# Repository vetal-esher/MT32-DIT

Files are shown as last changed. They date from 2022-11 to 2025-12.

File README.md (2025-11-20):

# MT32-DIT
<h3>Adding digital output to legendary Roland MT-32</h3>
<p>Project status: ⬛⬛⬛⬛⬛⬛⬛⬛⬛⬛⬛⬛⬜ 95%</p>
<p>
This project can be considered part #2 of the digitalization of old synthesizers. In the first part I described <a href="https://github.com/vetal-esher/18bit-DIT">how you can add a  digital outpu</a>t to almost any synthesizer (where the DAC circuit uses standard L/R combined I2S) by using the AK4103AVF</p>

<p>
Roland MT-32, familiar to old gamers in the 90s and very rare now, is an even older device that uses a parallel DAC scheme that was 
quite common in Roland's D-series, which does not just convert the final stereo stream in-line, but also simultaneously performs 
the services of a DAC for the reverb IC.</p>

<h3>Digging demuxer logic</h4>

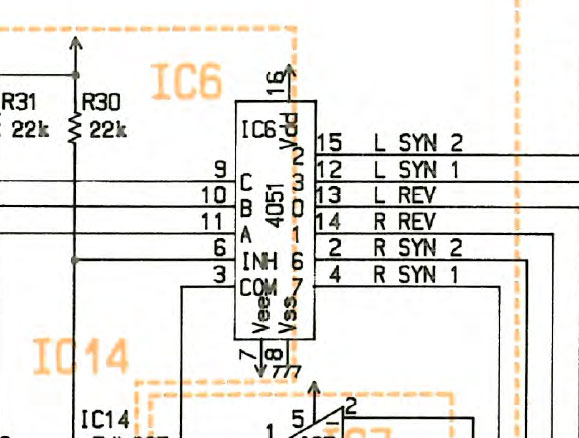
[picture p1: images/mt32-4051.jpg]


<p>
It turns out that we do not have direct access to the digital stream containing the final audio data. The PCM54HP receives a stream 
that sequentially contains not only clean left and right channels, but also separate reverb data for the left and right channels. 
It looks something like this (all frames are 16bit, order is assumed): [RSYN1][LSYN1][REV R][REV L][RSYN2][LSYN2][RSYN1][LSYN1][REV R][REV L][RSYN2] [LSYN2] etc.</p>
<p>
The advantage of a parallel DAC is that it works instantly, i.e. there is no delay at all in taking the current values 
from the (essentially) resistor assembly and the next moment doing the task of transforming a completely different picture. <strong>Edit: 
to tell the truth, there IS small delay required to let the output settled the final value.</strong>
</p>
<p>The widely known CD4051 is engaged in demultiplexing all this porridge of audio data. Channel switching in the CD4051 is carried out 
through the control lines mixed from LA and Reverb chips SH1 SH2 SH2 (SH - Sample / Hold), as well as the INH line, which turns on and off 
all channels. At the output of the demuxer, three pairs of analog channels are formed, which are then mixed and undergo final 
processing in a low-pass filter. The LP filter should have a flat amplitude response in the 0-20kHz range and a high attenuation above 20kHz.
</p>

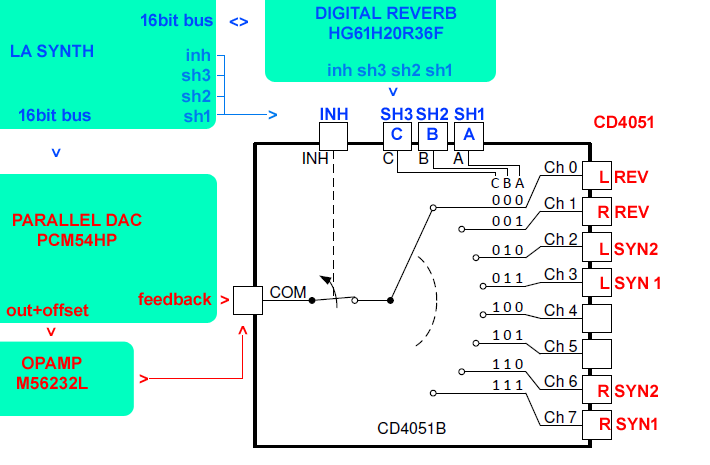
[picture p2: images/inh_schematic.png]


<p>
Bit depth and sampling frequency of MT-32 according to the declared characteristics - 15bit 32kHz. In the first version of MT-32 
(the so-called "old"), the last (actually, LSB) 16th bit at the PCM54HP input is shorted to ground, and for that (15bit) reason the 14th bit fell out 
in the data bus itself (counting from zero). However, for us, the frame width will always be 16 bits (the 2nd MT-32 version has full 16bit bus). Theoretically, the channel  switching frequency 0-1-2-3-4-5-6-7 each time triggers a 0/1 state change in control signal A, so you can 
expect 128kHz on this line,  64kHz on line B, and C with 32kHz respectively. But we don't know the order of the frames. Even if we 
sequentially record all the states of the parallel bus, it will be useless if we do not know the order of switching ABC. In practice, 
without a three-channel oscilloscope, you can try to catch the states of at least two of the three lines (A and C), and then record 
the AB and BC, A and INH sequences in order to further bring the picture into one.
</p>
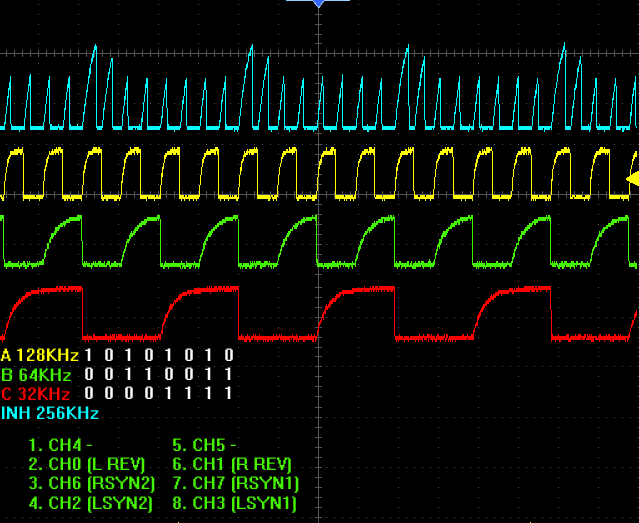
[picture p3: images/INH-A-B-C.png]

<p>

So now we know the frame order: [L REV][RSYN2][LSYN2][R REV][RSYN1][LSYN1], [L REV][RSYN2][LSYN2][R REV][RSYN1][LSYN1] .. etc. 
If you listen to these pins in analog, it becomes clear that SYN1 is a clean signal, REV is a reverb return. SYN2 appears to be 
analog as well, but too quiet to be recorded legibly; but since SYN2 is also mixed into the final mix, we'll do that too. 
By the way, if you look at the unused outputs of the CD4051 CH4 and CH5, there will be [almost] crisp 32kHz:

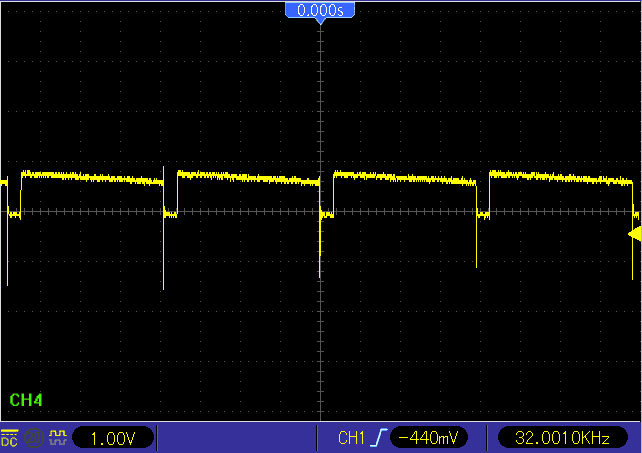
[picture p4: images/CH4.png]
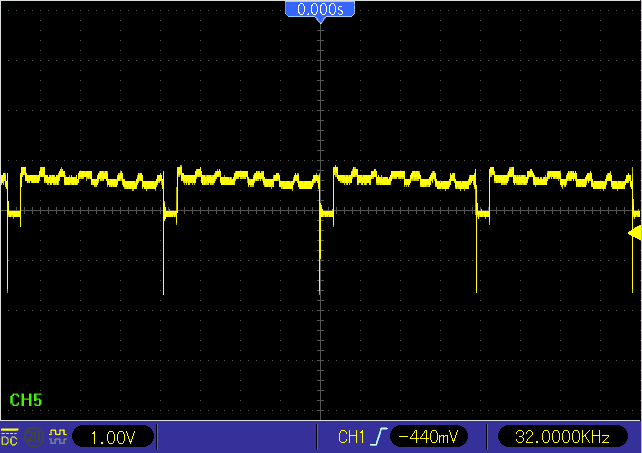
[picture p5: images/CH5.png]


<p>The INH control signal operates at a frequency of 256kHz, which means we will need to read all ports at this frequency. 
Disabling all channels is necessary so that there is no false triggering on rising edges @ABC states, when INH=1 tells us that 
we don’t need to send anything to serial. With INH=0, we must read the bus, and depending on the states of ABC, scatter it to 
the appropriate output. Ideally, we need to define the beginning of frame (we take the highest INH peak for the reference frame)
and mix all L / R frames into two final ones. But for the test, you can start by sending two frames with a clean non-reverberated 
information (RSYN1, LSYN1). At first I thought to bother with the sequence' start detection, but then I omitted this part, because,
even if the logic begins to run in the middle, defining LSYN1 as the end of the sequence we will reset the counters and then start 
working in the correct order. The logic in this case will look something like this (I will use a pseudo-language here with a syntax 
that is clear to everyone):</p>

<pre>
(R,L)=(0,0);
(FLAG_RSYN1,FLAG_LSYN1,FLAG_RSYN2,FLAG_LSYN2,FLAG_RREV,FLAG_LREV)=(0,0,0,0,0,0);
(RSYN1,LSYN1,RSYN2,LSYN2,RREV,LREV)=(0,0,0,0,0,0);
while (256kHz_cycle) {
	input=read(PCM54_parallel);
	A=read(CD4051_A); B=read(CD4051_B); C=read(CD4051_C); INH=read(CD4051_INH);

	#INH==0 enables output
	if (INH==0) {
		if (A==1 && B==1 && C==0) {
			RSYN2=input; FLAG_RSYN2=1; #RSYN2
		}
		elsif (A==0 && B==1 && C==0) {
			LSYN2=input; FLAG_LSYN2=1; #LSYN2
		}
		elsif (A==0 && B==0 && C==1) {
			RREV=input; FLAG_RREV=1;   #RREV
		}
		elsif (A==0 && B==0 && C==0) {
			LREV=input; FLAG_LREV=1;   #LREV
		}
		elsif (A==1 && B==1 && C==1) {
			RSYN1=input; FLAG_RSYN1=1; #RSYN1
		}
		elsif (A==0 && B==1 && C==1) {
			LSYN1=input; 		   #LSYN1 this is the last channel in frame
			(FLAG_RSYN1,FLAG_LSYN1,FLAG_RSYN2,FLAG_LSYN2,FLAG_RREV,FLAG_LREV)=(1,1,1,1,1,1);
		}

		if (FLAG_RSYN1==1 && FLAG_LSYN1==1 && FLAG_RSYN2==1 && FLAG_LSYN2==1 && FLAG_RREV==1 && FLAG_LREV==1) {

			#in merge there will be magic
			L=merge(LSYN1,LSYN2,LREV);
			R=merge(RSYN1,RSYN2,RREV);
			write_serial(R,L); 

			#reset channel flags
			(FLAG_RSYN1,FLAG_LSYN1,FLAG_RSYN2,FLAG_LSYN2,FLAG_RREV,FLAG_LREV)=(0,0,0,0,0,0);
		}
	}
}
</pre>

<h3>Hardware part</h3>

<p>Schematically, the plan of the entire project was drawn like this:</p>
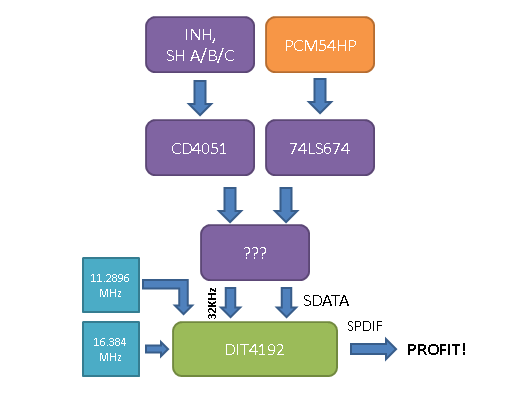
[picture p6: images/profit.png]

<p>
There is only one magic figure involved in this plan, and here, I will honestly say, giant constructions of logic which must perform the task of mixing digital streams comes to mind. I was told that I should stop doing garbage and learn a programmable FPGA. All of the DAC and INH/A/B/C signals are CMOS-level, so we need to convert them to TTL by CD4050B. By the way, we will get fixed levels of INH after CD4050:
</p>
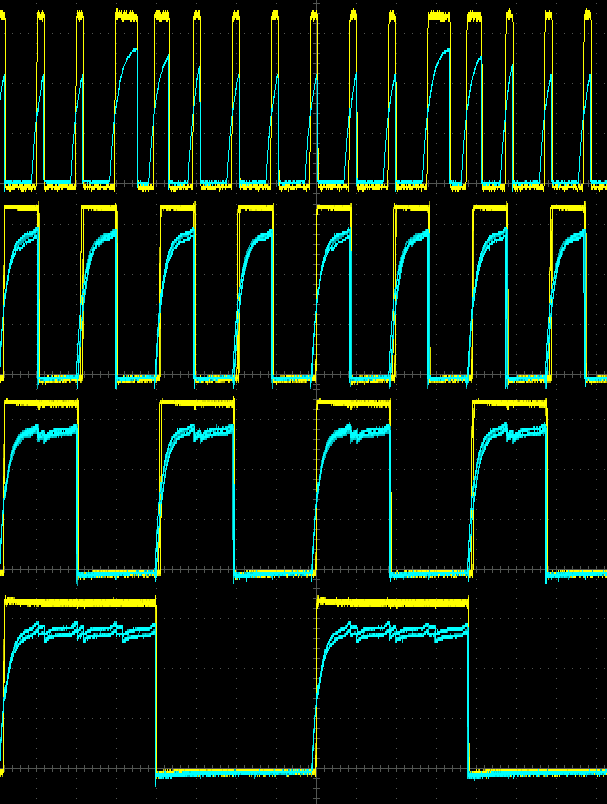
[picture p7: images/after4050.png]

<h4>DIT</h4>
<p>
Since we are dealing with 16 bits, a large number of DITs can be used, as they all work at least with 16-bit RJ. For these purposes, I chose DIT4192, because I have it  already available after experimenting with the 18-bit DIT, but you can skip mounting 4192 if you don't have it (details below). Settings are typical:
<table border="1">
<tr><th colspan="2">DIT4192 Hardware mode</th></tr>
<tr><td>Mode operation</td><td>Slave (SYNC and SCLK are inputs)</td></tr>
<tr><td>Format</td><td>16-Bit Right-Justified</td></tr>
<tr><td>Sampling frequency</td><td>32kHz</td></tr>
<tr><td>Master clock</td><td>16.384MHz (512*fs)</td></tr>
<tr><td>Bit clock</td><td>1.024MHz (16*2*32KHz)</td></tr>
</table>
</p>

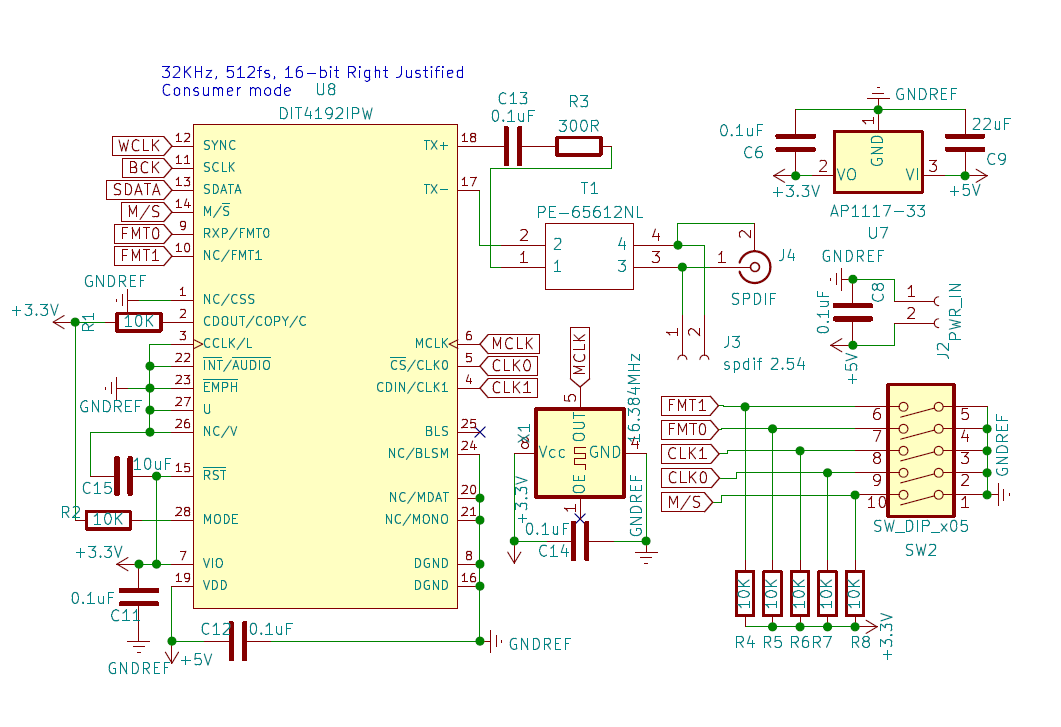
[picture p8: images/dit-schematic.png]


<h3>Magic part</h3>
<p>The FPGA <a href="https://wiki.sipeed.com/hardware/en/tang/Tang-Nano-9K/Nano-9K.html">TangNano9K</a> was chosen for the magic part, so the "profit" plan was drawn:</p>
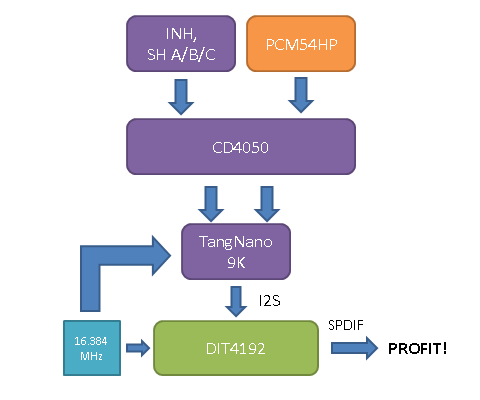
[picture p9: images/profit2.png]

<p>And then the complete schematic of the "magic" part was done. Note the I2S connector, you can completely skip DIT4192 in schematic and use your favorite external DIT, or even just transport I2S to I2S receiver. I tested I2S with external WM8804 DIT board and it works perfectly.</p>
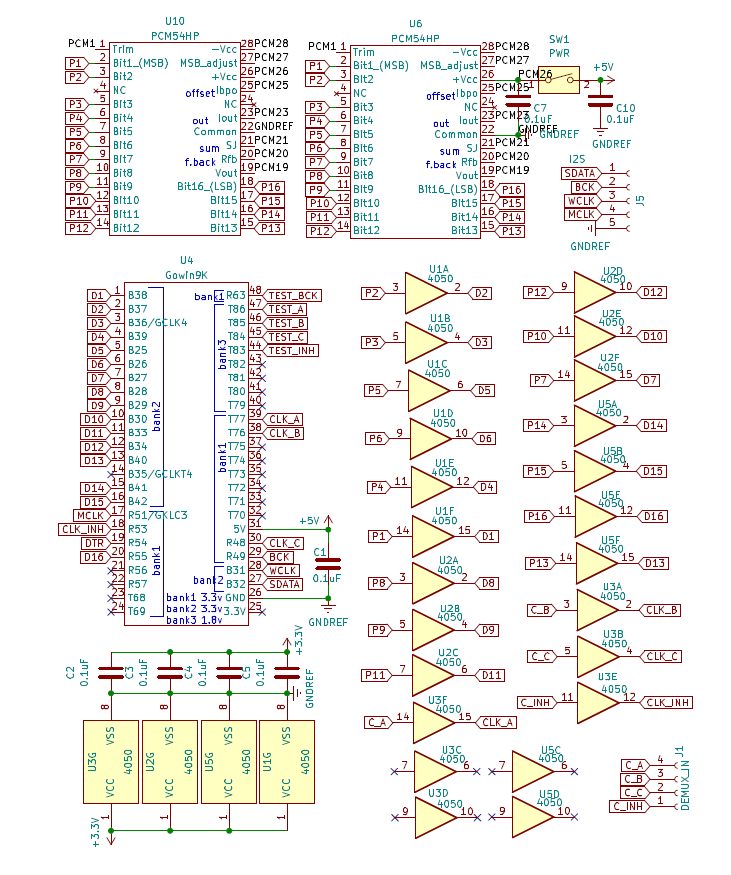
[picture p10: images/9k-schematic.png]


<h3>Making prototypes</h3>
<p>I started with sandwich-like breadboard, trying to split the CMOS-TTL logic from TangNano. Different methods, using couple of variants (voltage dividers) and CD4050 were tried..</p>
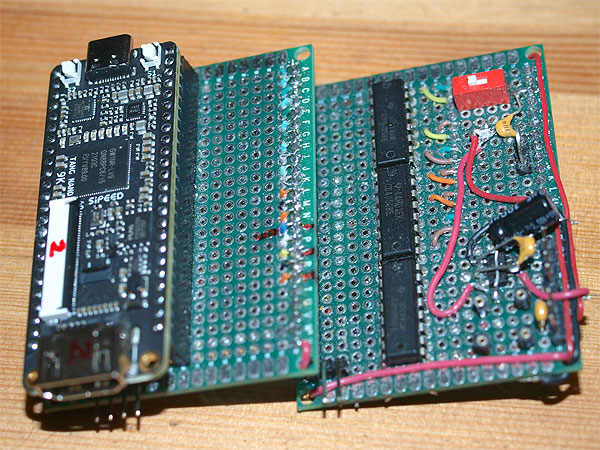
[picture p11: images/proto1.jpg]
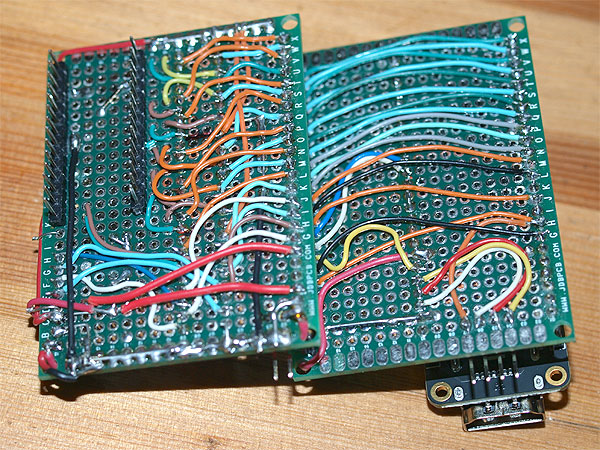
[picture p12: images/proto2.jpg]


.. and then, when i finally decided to use CD4050, i have projected the PCB. The PCBs were made quick at PCBway factory, and i must say their quality is awesome, even for such pet projects like mine :) 

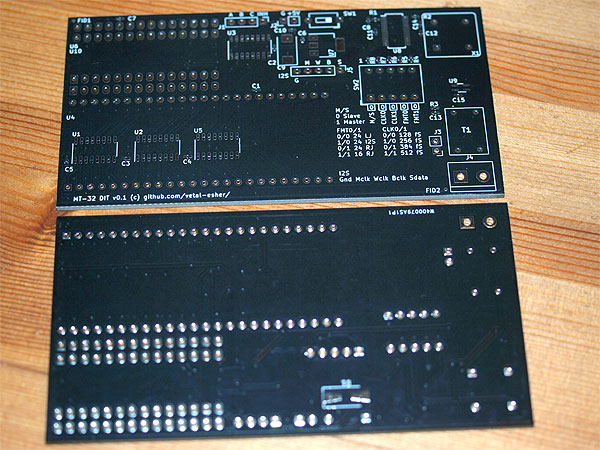
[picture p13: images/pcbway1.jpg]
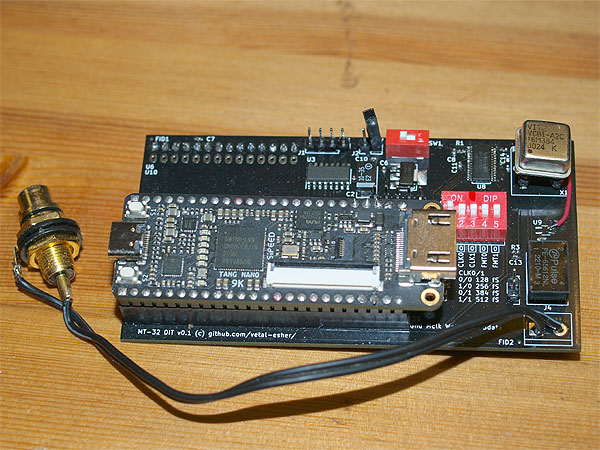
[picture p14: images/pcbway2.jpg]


<p>Final design assumes, that the original PCM54HP will be desoldered from MT-32 mainboard, and then socketed on second footprint right on DIT pcb. After that, MT32-DIT can be soldered or socketed on MT-32 mainboard. But for now, we'll just put on the DIT board right over PCM54HP IC.</p>

<h2>Partlist</h2>
<table border=1>
	<tr><th>Reference</th><th>Total</th><th>Value</th><th>Package</th></tr>
	<tr><td>X1</td><td>1</td><td>16.384MHz</td><td>Oscillator DIP-8</td></tr>
	<tr><td>U1, U2, U3, U5</td><td>4</td><td>CD4050</td><td>SO-16</td></tr>
	<tr><td>U4</td><td>1</td><td>Gowin 9K</td><td></td></tr>
	<tr><td>U6</td><td>1</td><td>PCM54HP**</td><td>DIP-28</td></tr>
	<tr><td>U8</td><td>1</td><td>DIT4192IPW***</td><td>SSOP-28</td></tr>
	<tr><td>U7</td><td>1</td><td>AP1117-33</td><td>SOT223-3_TABPIN2</td></tr>
	<tr><td>U10</td><td>2</td><td>PinHeader 1x28</td><td>P2.54mm</td></tr>
	<tr><td>T1</td><td>1</td><td>PE-65612NL***</td><td>PE-65612NL</td></tr>
	<tr><td>SW1</td><td>1</td><td>PWR SW</td><td>SW_DIP_SPSTx01_P2.54mm</td></tr>
	<tr><td>SW2</td><td>1</td><td>CFG SW***</td><td>SW_DIP_SPSTx05_P2.54mm</td></tr>
	<tr><td>R1, R2, R4, R5, R6, R7, R8</td><td>7</td><td>10K ***</td><td>0402</td></tr>
	<tr><td>R3</td><td>1</td><td>300R ***</td><td>0402</td></tr>
	<tr><td>J1</td><td>1</td><td>PinHeader 1x04</td><td>P2.54mm</td></tr>
	<tr><td>J2, J3***</td><td>2</td><td>PinHeader 1x02</td><td>P2.54mm</td></tr>
	<tr><td>J4</td><td></td><td>DNP*</td><td></td></tr>
	<tr><td>J5</td><td>1</td><td>PinHeader 1x05</td><td>P2.54mm</td></tr>
	<tr><td>C1, C2, C3, C4, C5, C6, C7, C8, C10, C11, C12***, C13***, C14</td><td>13</td><td>0.1uF</td><td>0402</td></tr>
	<tr><td>C15***</td><td>1</td><td>10uF</td><td>0402</td></tr>
	<tr><td>C9</td><td>1</td><td>10-22uF</td><td>CP_EIA-7343-43</td></tr>
</table>
<p>If only specific component can be skipped, it's marked within "Reference" column, otherwise all components can be skipped if mark is in "Value" column.</p>
<p><strong>*</strong> - Do Not Place</p>
<p><strong>**</strong> - optional, no need if DIT pcb soldered on top of the original DAC</p>
<p><strong>***</strong> - optional, no need if DIT4192 is not available and you use external DIT</p>

<h3>Learning VERILOG</h3>

<p>I did not have any experience in designing FPGA projects, and did not knew about verilog language anything. But it appeared, that my pseudo-language logic described above is almost verilog-like! So, after few weeks, the very first working code was written.</p>

<details>
  <summary>First verilog code:</summary>	

<pre>
module top (
        input mclk,             //master clock //pin 51
        input clk_inh,          //256kHz INH clk input //pin 53
        input [2:0] ch_id,      //cd4051 sample/hold controls a/b/c 128/64/32kHz //pin a 77 b 76 c 48
        input [15:0] dac,       //parallel input from dac
	input sys_rst_n,        //reset input
	output wire dtr,        //data ready flag //pin54
        output sdata,           //16bit i2s sdata output  //pin 49
        output wire wclk,       //i2s word select lrck output 32kHz //pin 31
        output wire bck         //i2s bit clock output 1024MHz //pin32
);

wire [31:0] data;

dac_decoder dac1(
	.clk_inh(clk_inh),.ch_id(ch_id),.dac(dac),.data(data),.rst_n(sys_rst_n),.dtr(dtr)
);

i2s_serializer ser1 (
	.mclk(mclk),.sdata(sdata),.wclk(wclk),.bck(bck),.data(data),.rst_n(sys_rst_n)
);

endmodule

module i2s_serializer (
        input mclk,             	//master clock 16.384MHz
	input [31:0] data,		//input channels register 
	input wire rst_n,		//reset button	
	output reg sdata,   	    	//i2s sdata output
        output reg wclk,        	//i2s word select lrck output mclk/512 = 32kHz
        output wire bck         	//[3] bit'mclk. i2s bit clock output 
					//16bit * 2 * 32000 = 1.024 MHz (16.384/16)
);
reg [31:0] mclk_counter;       		//32bit counter
assign bck=mclk_counter[3];     	//1.024MHz divide
reg [31:0] data_buf;			//i2s output buffer 
reg [4:0] cbit;				//0-15 current bit counter
			
initial begin
	mclk_counter<=0; cbit<=0; wclk<=0; data_buf<=0;
end

always  @(posedge mclk,negedge rst_n) begin
	if(!rst_n) begin mclk_counter<=0; end 
	else begin mclk_counter<=mclk_counter+1; end
end

//i2s WCLK=0 left, =1 right
always  @(negedge bck) begin					//send sdata from buffer
	if (wclk==0) begin sdata<=data_buf[31-cbit]; end 	//LSYN send
	else if (wclk==1) begin sdata<=data_buf[15-cbit]; end	//RSYN send
	cbit<=cbit+4'b01;
	if (cbit==15 && wclk==0) 
		begin cbit<=0; wclk<=1; end			//LSYN1 end
	else if (cbit==15 && wclk==1) 
		begin cbit<=0; wclk<=0; data_buf<=data; end 	//RSYN1 end, new buffer read
end
endmodule

module dac_decoder (
	input wire rst_n,
        input clk_inh,          	//256kHz INH clk input
        input [2:0] ch_id,    		//cd4051 sample/hold controls a/b/c
        input [15:0] dac,       	//parallel input from dac
	output reg [31:0] data,		//32 bit
	output reg dtr			//data ready flag
);
reg [15:0] ch0;				//LREV
reg [15:0] ch6;				//RSYN2
reg [15:0] ch2;				//LSYN2
reg [15:0] ch1;				//RREV
reg [15:0] ch7;				//RSYN1
reg [15:0] ch3;				//LSYN1
initial begin
	ch0<=0; ch1<=0; ch2<=0; ch3<=0; ch6<=0; ch7<=0; dtr<=0; data<=0;
end

always  @(negedge clk_inh,negedge rst_n) begin
	if(!rst_n) begin
		dtr<=0; data<=0;
	end 
	else begin
	case (ch_id)
		4 : begin dtr<=0; end 			// empty
		0 : begin dtr<=0; ch0<=dac; end 	// LREV
		6 : begin dtr<=0; ch6<=dac; end 	// RSYN2 
		2 : begin dtr<=0; ch2<=dac; end 	// LSYN2
		5 : begin dtr<=0; end 			// empty
		1 : begin dtr<=0; ch1<=dac; end 	// RREV
		7 : begin dtr<=0; ch7<=dac; end 	// RSYN
		3 : begin dtr<=1; ch3<=dac; data = {dac,ch7}; end // LSYN
	endcase
	end
end
endmodule
</pre>

</details>

The <a href="https://www.youtube.com/watch?v=VIkrG32c1l0">first video</a> of clean capture (sorry for low volume, it was at night) (clean stereo, no reverb).

<h3>Mixing 6 digital channels to stereo pair</h3>

The simplest logic of audio mixing is summing the levels. This works in digital too. Remember, that actual bitwidth of "old" Roland MT-32 is 15 (LSB bit is tied to the GND. So, 
we can use 17-bit buffer to sum all 3 channels. Also i implemented "reverb on/off" switch tied to second button at TangNano9K devboard (first one is RESET button). 
OFFSET parameter used to avoid digital overflow problem when summing all channels.

<pre>
reg signed [15:0] lsyn1, lsyn2, rsyn1, rsyn2, rrev;	//channels from LA32 and Reverb ICs
reg signed [15:0] left,right;
reg signed [16:0] l,r;

initial begin
    data<=0; rrev<=0; rsyn1<=0; lsyn2<=0; rsyn2<=0; 
    l<=0; r<=0; left<=0; right<=0; dtr<=0;
end

localparam signed [15:0] OFFSET = 16'd8192; //Digital DC offset fix

always  @(negedge clk_inh) begin
	if (!rst_n) begin
		data<=0; dtr<=0;
	end else begin
	case (ch_id)
     		7 : begin // RSYN1
			rsyn1<=dac; dtr<=1;
			left <= l[15:0]-OFFSET; right <= r[15:0]-OFFSET;
		    end 
		6 : begin rsyn2<=dac; dtr<=0; end // RSYN2
		5 : begin data<={left,right}; dtr<=0; end // empty
		4 : begin dtr<=1; end // empty
		3 : begin lsyn1<=dac; dtr<=1; end // LSYN1
		2 : begin lsyn2<=dac; dtr<=1; end // LSYN2
		1 : begin rrev<=dac;  dtr<=1; end // RREV
		0 : begin dtr<=0; // LREV
			if (!rev_sw) begin  l<=lsyn1; r<=rsyn1;  end else 
			begin l<=lsyn1+lsyn2+dac; r<=rsyn1+rsyn2+rrev; end
 	     	end 
	endcase
	end
end

</pre>
</details>

<h3>Possible problems</h3>

<h4>Clicks</h4>
<p>At the final stage, i found that the frequency of DTR (the flag that signals about full frame cycle pass) is slightly faster than WCLK (smth about 32.0010kHz@DTR vs exact 32.0000kHz@WCLK). 
I
</p>



<p>The first reason is that you cannot operate with registers with multiple actions in one clock tick. You need pipeline. So, mixing logic with OFFSET must be separated.

Also, within this logic, you need to avoid update output data register when it might be in "read status" at serializer. Setting values need some time to be set, so we don't update the data when it is in stage of reading.

<p>After that, recording more than 3 hours showed that the clicks were gone, completely.</p>
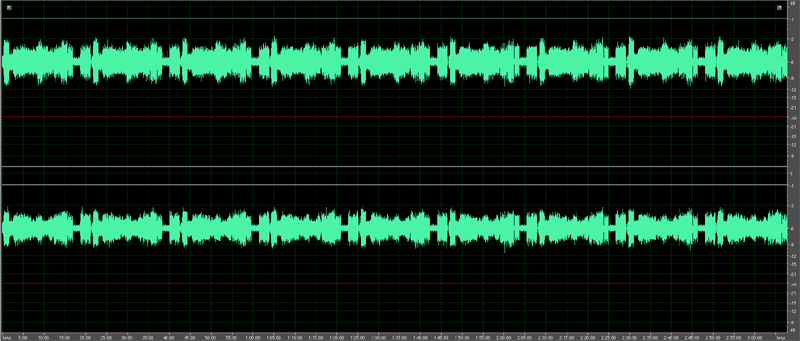
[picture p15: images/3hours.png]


<h4>Desync</h4>
<p>Another problem can appear, there <strong>might be</strong> desync that can produce more clicks than useful audio data. The source of problem is in unstable crystal oscillator - you need to check the DIT pcb for shorts and leakages. </p>
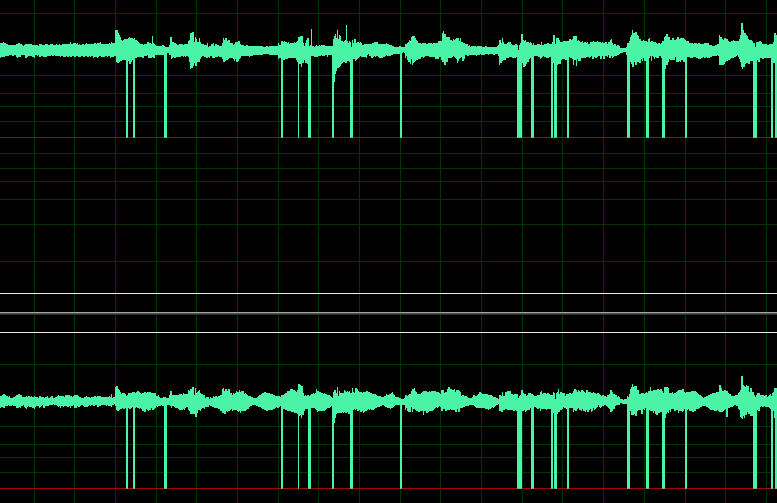
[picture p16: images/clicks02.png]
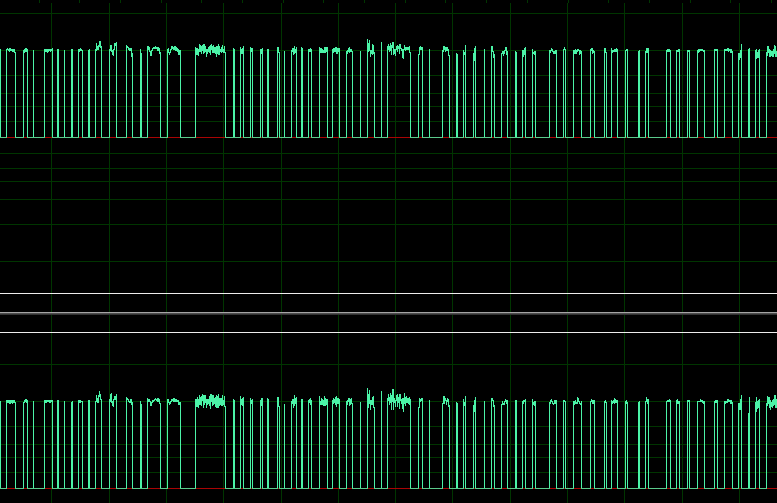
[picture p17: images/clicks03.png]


<h4>Digital DC offset</h4>

<p><strong>Updated 15.10.2025</strong></p> It's seems that there's nothing we can do (at least with 1st revision of MT-32) since DAC's LSB bit is tied to ground and there is 14 bit dropped in DAC schematic. When LSB bit will be used, there will be no DC offset at all. After all, i checked the PCB and found that the Bit14(=D14) used in schematic bus between LA32/Reverb/DAC - on real PCB has no route out from LA32 and Reverb chips, and the pin 27 (D14) on LA32 has no activity on oscilloscope at all.
You can slightly lower DC offset decrementing each sample value by 16344 (that the value of amplitude zero when there's no sound from MT-32), but this will give you only 6dB fix.
</p>

<h4>Post digital LPF processing</h4>

<p><strong>To be continued</strong></p>

<h2>Mounting</h2>

<strong>Bad contact problem.</strong> It was nightmare to spend hours to find the source of noisy sound. After weeks(!) of resultless tries, i found that the way i put the pcb over original DAC is not reliable at all - some pins was not connected . 

<p><strong><a href="audio/clean.mp3">Example of clean sound.</a></strong></p>
<p><strong>And <a href="audio/dirty_1.mp3">this is what you should hear</a> when some bits are not connected</strong></p>

<p>To avoid bad contact problem, the only way is to desolder DAC and socket it on the MT32-DIT pcb. This process is very hard without proper experience. First of all, you need to replace nearby caps with lower profile equivalents. Film caps are perfectly fit this objective. Then desolder the DAC itself.</p>

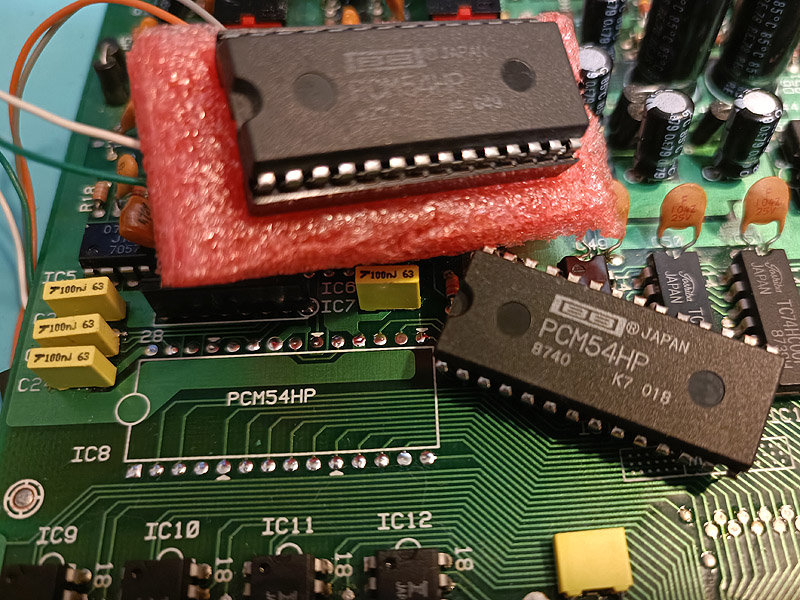
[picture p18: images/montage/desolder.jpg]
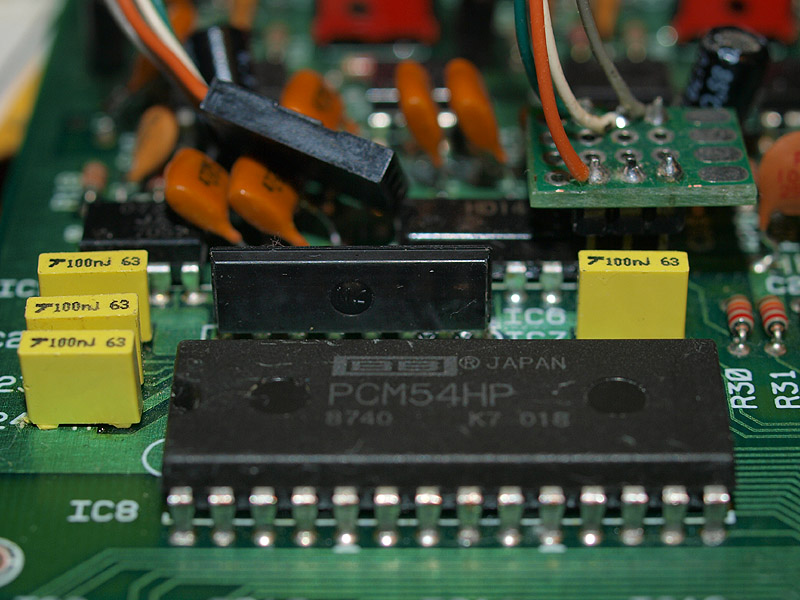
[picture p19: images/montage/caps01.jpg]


<p>While replacing the caps, it is time to think about picking A/B/C/INH directly from CD4051 demuxer. When you solder wires directly to DIP-package pins, wires tend to break when they bend, so i decided to solder a small protoboard over CD4051 for easy access to this signals.

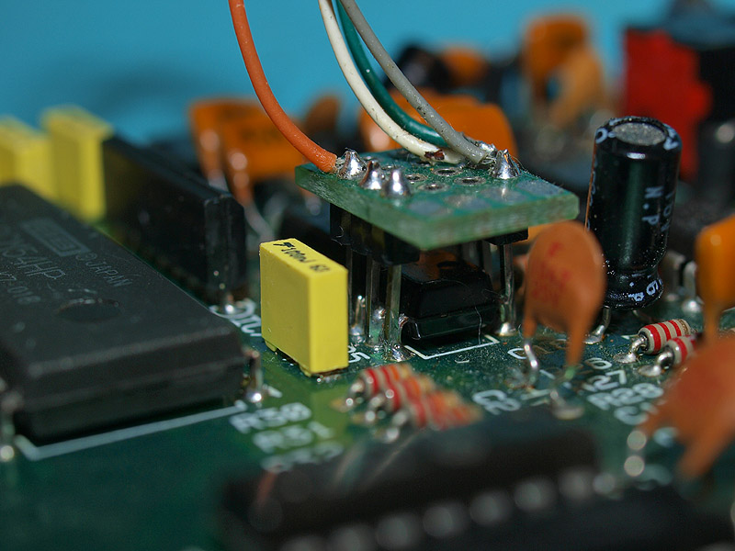
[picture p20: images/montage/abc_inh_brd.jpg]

<p>I used PBD (2-row) 2.54 female headers for socketing the DIT pcb in DAC place. One row, of course, needs to be removed. Why 2-row? Just because i had much more PBD headers than PBS. You can use PBS if you want. Then socket the PCM54HP on DIT pcb.</p>

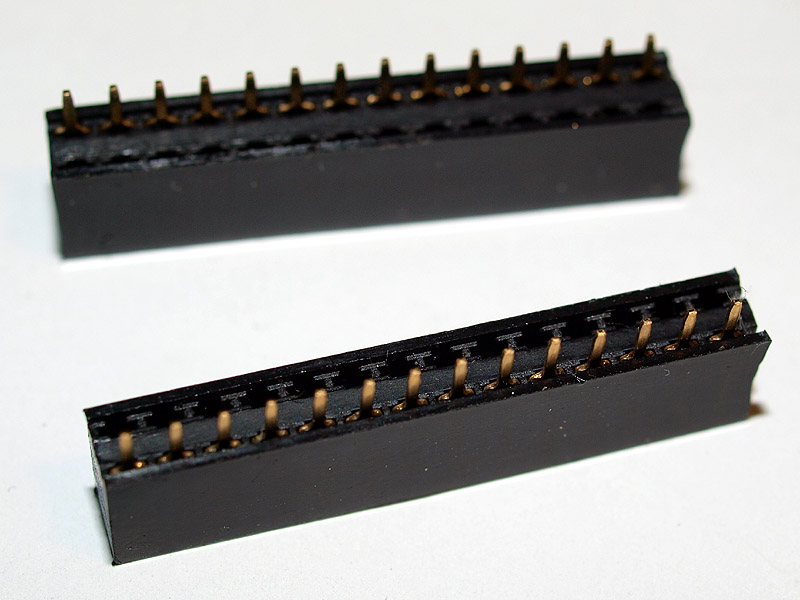
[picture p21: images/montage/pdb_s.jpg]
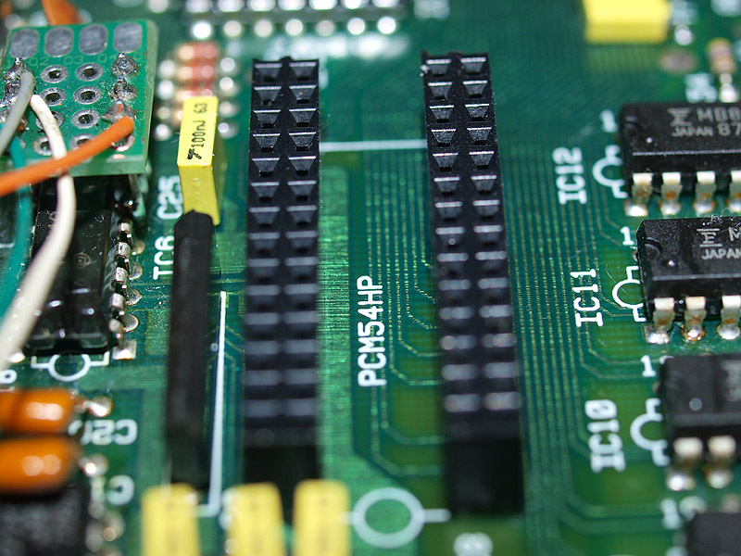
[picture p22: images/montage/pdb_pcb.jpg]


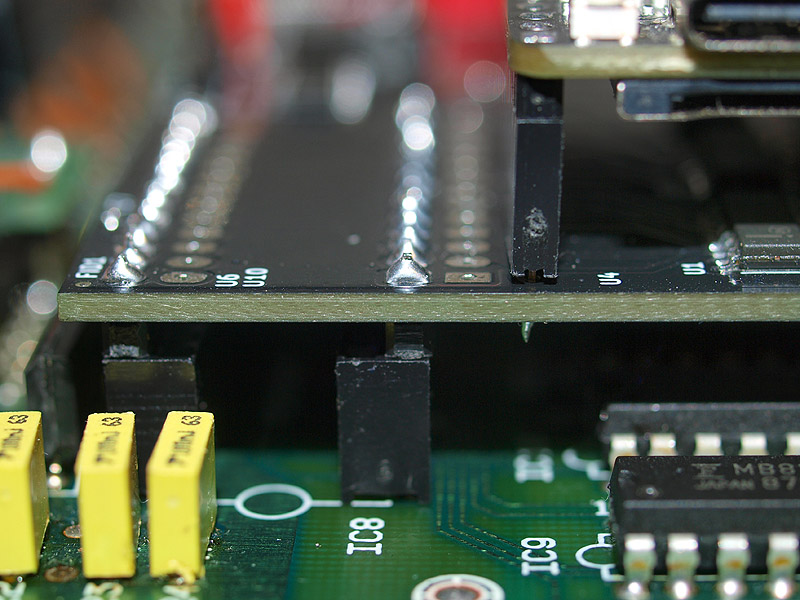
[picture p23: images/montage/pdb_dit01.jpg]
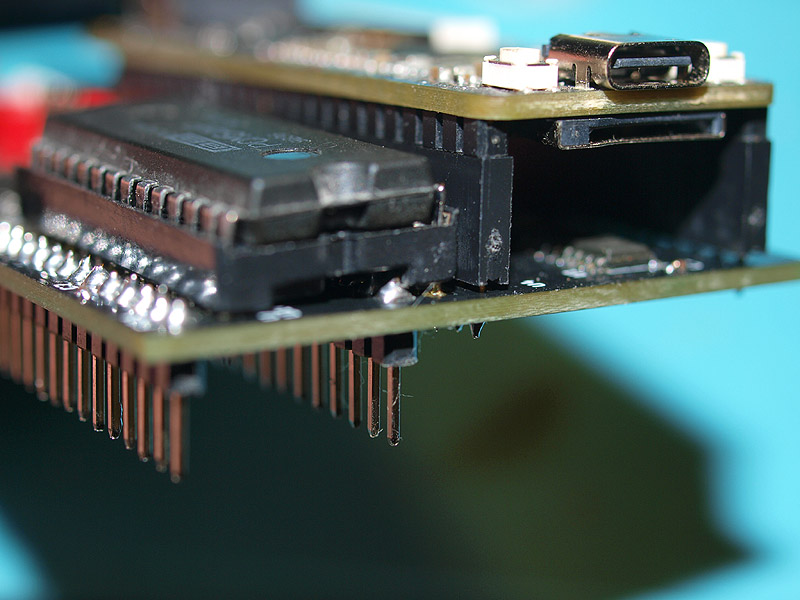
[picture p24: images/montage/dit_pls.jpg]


<p>Remove the MT-32 board from the case. It's time to drill a hole and mount RCA. Find the place where you want it.</p>

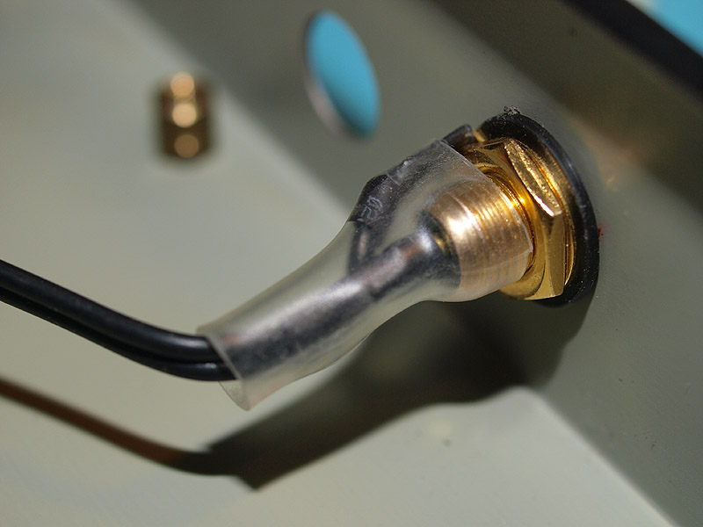
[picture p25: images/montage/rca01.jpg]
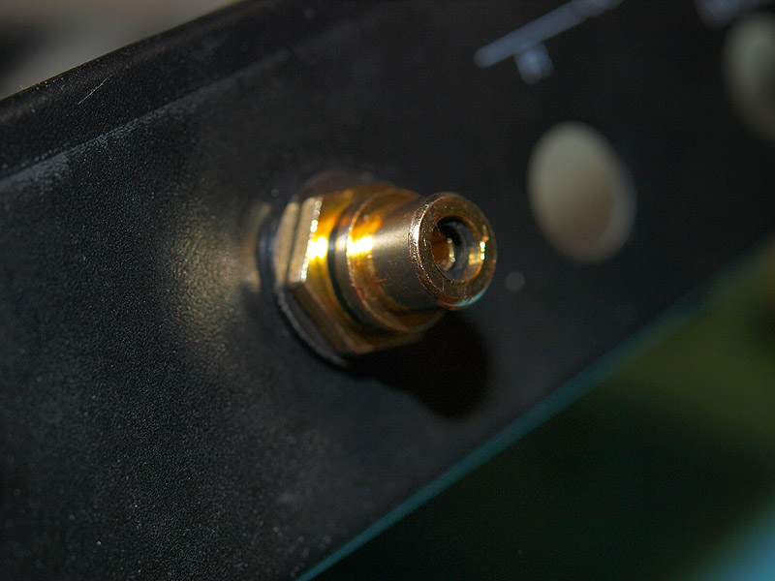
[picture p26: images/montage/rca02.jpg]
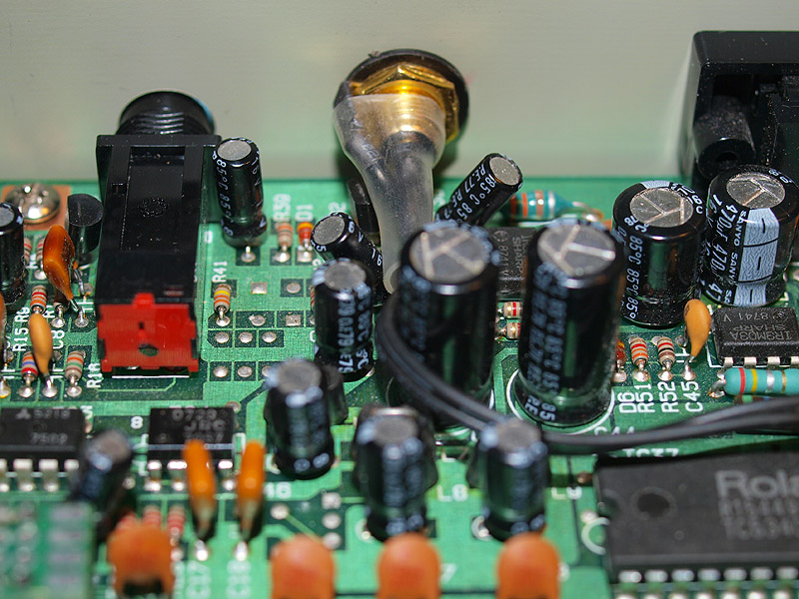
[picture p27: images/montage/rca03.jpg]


<p>Final picture:</p>

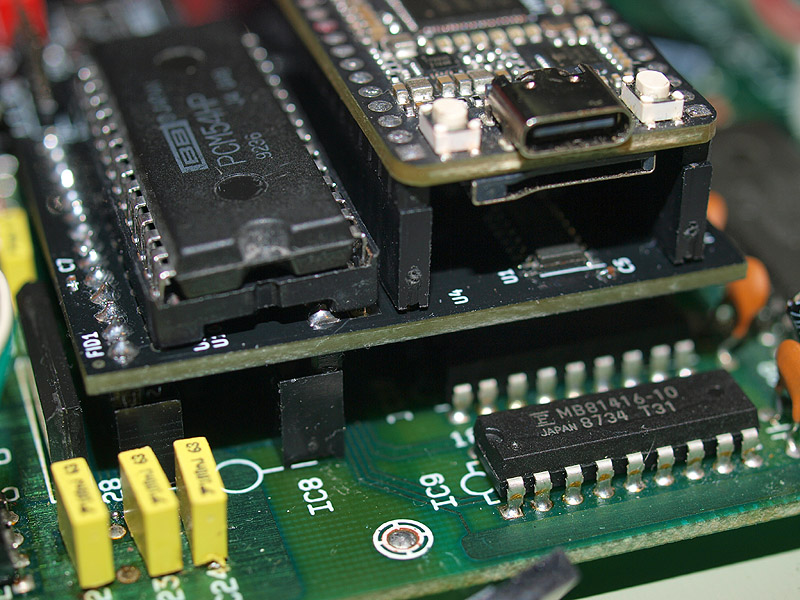
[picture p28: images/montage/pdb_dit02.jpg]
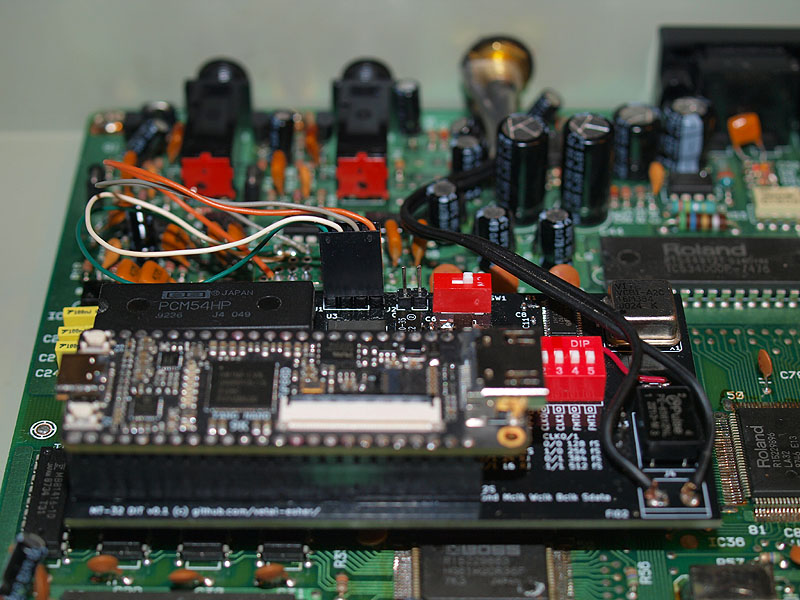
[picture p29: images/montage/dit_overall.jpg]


<h3>Links</h3>

<p><a href="https://github.com/vetal-esher/MT32-DIT/blob/main/hardware/datasheets/mt-32_Service_Notes_First_Edition.pdf">Roland MT-32 service notes</a></p>
<p><a href="https://github.com/vetal-esher/MT32-DIT/blob/main/hardware/datasheets/pcm54.pdf">PCM54HP datasheet</a></p>
<p><a href="https://github.com/vetal-esher/MT32-DIT/blob/main/hardware/datasheets/hd14051bp.pdf">4051 datasheet</a></p>
<p><a href="https://github.com/vetal-esher/MT32-DIT/blob/main/hardware/datasheets/cd4050b.pdf">CD4050B datasheet</a></p>
<p><a href="https://github.com/vetal-esher/MT32-DIT/blob/main/hardware/datasheets/dit4192.pdf">DIT4192 datasheet</a></p>
<p><a href="https://github.com/vetal-esher/MT32-DIT/blob/main/hardware/datasheets/I2SBUS.pdf">I2S bus specification</a></p>

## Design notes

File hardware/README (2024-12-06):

In 0.4 version the project was splitted into two:

1. MT32-DIT-v0.4
Main board designed with TangNano 9K support. 
Small noise reduction mod is also added according to PCM54HP datasheet.
I2S pins moved to top right corner.

2. MT32-DIT-board

Small two-sided board with DIT4192 or WM8804 support. You can solder only one side with preferrable DIT IC and connect into I2S connector @MT32-DIT-module.

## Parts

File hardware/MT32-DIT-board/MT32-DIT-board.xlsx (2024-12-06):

Designator | Q-ty | Designation | Package
C2,C4,C6,C13,C14,C1,C7,C15,C12,C11,C3,C8,C5,C10 | 14 | 0.1uF/16V | C0402
C9 | 1 | 22uF/10V | CP7343
R3 | 1 | 300R/1% | R0402
R8,R1,R4,R5,R6,R2,R7 | 7 | 10K/1% | R0402
U2,U5,U3,U1 | 4 | CD4050 | SO-16
U6 | 1 | PCM54HP | PCM54
U8 | 1 | DIT4192IPW | SSOP-28
U7 | 1 | AP1117-3.3 | SOT-223-3
U9 | 1 | ADM6713 | SOT-343
U4 | 1 | Gowin9K | DIP-48
T1 | 1 | PE-65612NL | PE65612NL
D1 | 1 | 1N4148 | SMA
J3 | 1 | spdif 2.54 | PinHeader_1x02
J5 | 1 | I2S | PinHeader_1x05
J1 | 1 | DEMUX_IN | PinHeader_1x04
J2 | 1 | PWR_IN | PinHeader_1x02
SW1 | 1 | SW_PWR | SW_DIP_SPSTx01
SW2 | 1 | SW_CFG | SW_DIP_SPSTx05
X1 | 1 | 16.384MHz | Osc_DIP-8

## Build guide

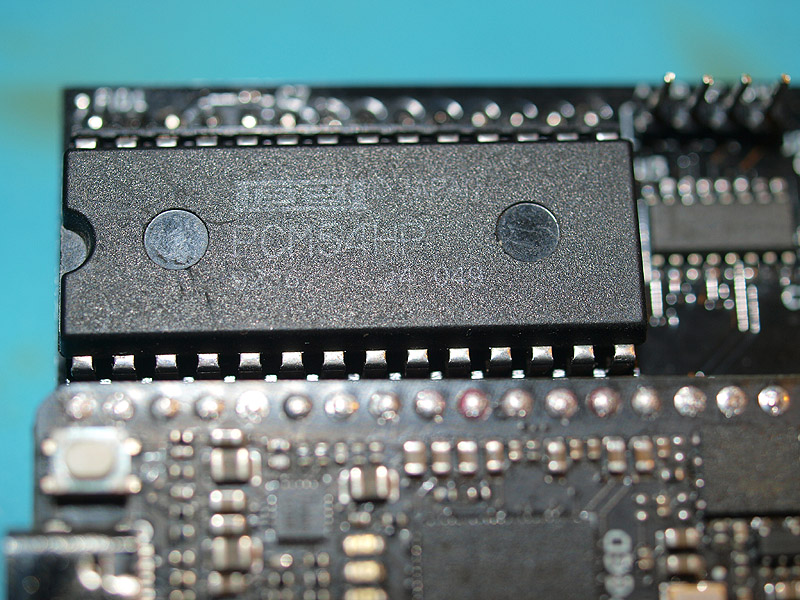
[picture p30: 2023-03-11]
images/montage/pcm_dit.jpg

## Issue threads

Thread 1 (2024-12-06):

Interest in project files

skadarnold, 2024-12-06:
Hello, thank you for all of your hard work and research into this project. I find it very interesting and I am considering building this project or potentially adding to it. Would you have any interest in sharing the actual project files for this build? Any KiCad, source files, etc? With your documentation I can probably create everything but it would be easier having the project files since the work has already been done.

vetal-esher, 2024-12-06:
Thank you! Of course, Kicad project will be uploaded soon. I just need to clean the temporary files.

skadarnold, 2024-12-06:
Great! I am looking forward to checking everything out.

I noticed that you have configured the DIT4192  to right-justified I2S. Did you have to make any adjustments for this to work properly? It seems that the MT32 / PCM54HP might have used EIAJ standard which is close to right-justified but has slight differences with edge detection with the clock. I would be curious to know if the DIT4192 is able to clock this without any modification, and or if it is causing any sync problems or glitches in the audio output.

vetal-esher, 2024-12-06:
Kicad and Verilog files uploaded. The project is in the next stage, where the board splitted into FPGA and DIT parts, also small noise reduction mod is added according to PCM54HP datasheet.
PCM54HP is the parallel DAC, so its no left-or-right justified, you have all bits in the same time.
I use some kind of buffer frame where all channels is mixed then feed it to i2s serializer. Just take a look into verilog, it's simple.

vetal-esher, 2024-12-06:
These splitted board were checked to work - i produced the pcb's and installed them into MT32.

skadarnold, 2024-12-06:
Ok great. I knew it was a parallel DAC but wasn’t sure if the format carried over directly or not. I will spend some time looking it all over a little more when I get back home. I am not familiar with verilog yet but it looks fun and interesting. On Dec 6, 2024, at 10:46 AM, Victor Sergeev ***@***.***> wrote:
Kicad and Verilog files uploaded. The project is in the next stage, where the board splitted into FPGA and DIT parts, also small noise reduction mod is added according to PCM54HP datasheet.
PCM54HP is the parallel DAC, so its no left-or-right justified, you have all bits in the same time.
I use some kind of buffer frame where all channels is mixed then feed it to i2s serializer. Just take a look into verilog, it's simple.

—Reply to this email directly, view it on GitHub, or unsubscribe.You are receiving this because you authored the thread.Message ID: ***@***.***>

skadarnold, 2024-12-07:
The code is looking nice! I am understanding more of what is going on in the TangNano9k now. What are you using to compile the fs file? I have Gowin IDE but I do not see a project file.

vetal-esher, 2024-12-07:
If you have Gowin IDE, just start new project for the GW1NR-LV9QN88PC6/I5 and copy the sources to the project directory.
I have compiled .fs with GowinIDE, but also can approve that .fs can be synthesized with opensource yosis/nextpnr.

vetal-esher, 2024-12-07:
//Copyright (C)2014-2022 Gowin Semiconductor Corporation.
//All rights reserved.
//File Title: Bitstream file
//GOWIN Version: V1.9.8.10
//Device: GW1NR-9
//Device Version: C
//Part Number: GW1NR-LV9QN88PC6/I5
//Device-package: GW1NR-9C-QFN88P
//BackgroundProgramming: OFF
//CheckSum: 0xF573
//UserCode: 0x0000F573
//SPIAddr: 0x00000000
//LoadingRate: 2.500MHz
//CRCCheck: ON
//Compress: OFF
//Encryption: OFF
//SecurityBit: ON
//SecureMode: OFF
//JTAGAsRegularIO: OFF
//Created Time: Sat Jun 22 21:58:32 2024

skadarnold, 2024-12-08:
I will start playing around with this when I have a moment. I have a Tang Nano 9k in a different project I can borrow to try some things out, but it might take me a minute before will put a board together. I would like to change some things around a little to support left-justified or true I2S so that it can be directly compatible with a PCM5102 module which would be easy to use in place of the DIT4192 for use as a DAC, or make a module that supports both analog and digital.

vetal-esher, 2024-12-08:
The other problem you can meet - the digital DC offset problem. I cannot predict, what will be with the sound output of PCM5102 if one of the bits is missed and another is always zero. But, i can test, as i have PCM5102 from another project.

skadarnold, 2024-12-08:
Ok that is good to know! There probably isn't much of a reason to upgrade the DAC in this case as I agree it sounds good as it is. It is partly out of curiosity to be able to compare the DAC's. I have always heard that there can be added benefits to a 24bit DAC even on a 16bit wordclock. The analog portions would have a lower noise floor and I think the higher clock rate capabilities can allow for a less jitty clock at lower sample rates. I wouldn't mind hearing the differences and comparing their spec on the output.

skadarnold, 2024-12-08:
> The other problem you can meet - the digital DC offset problem. I cannot predict, what will be with the sound output of PCM5102 if one of the bits is missed and another is always zero. But, i can test, as i have PCM5102 from another project.

This would be cool to check. I have another project I am currently working on that will allow usage of the PCM5102 with 16bit and 18bit EIAJ like is used with the SC55 - SC88. I was also thinking about adding a DIT4192 module for easy digital out as well.

vetal-esher, 2024-12-08:
Out of curiosity, i have compared analog vs digital recordings from MT-32, and, except the digital DC offset, i see both recordings are quite comparable, if not identical. For Roland SC modules (and Yamaha as well), there is another mod with AK4103AVF, which is natively working with 18-bit i2s stream.

vetal-esher, 2024-12-08:
I approve that PCM5102 works with default I2S stream from Tangnano, as i plugged the board directly into I2S connector and hear the sound. Configured as left-justified.
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

skadarnold, 2024-12-08:
That is very cool! This is very versatile then, I will try to get the parts to build on the next order.

vetal-esher, 2024-12-08:
This board (MT32-DIT) is almost universal, i have some other project to add digital out to Alesis Micron, and the board fits all needs - many inputs and i2s output. The problem in Alesis Micron is that they used 32bit-wide I2S, it's not in standard at all, and there is no DIT's that support 32-bit I2S, because it's only 24-bit by specs :)

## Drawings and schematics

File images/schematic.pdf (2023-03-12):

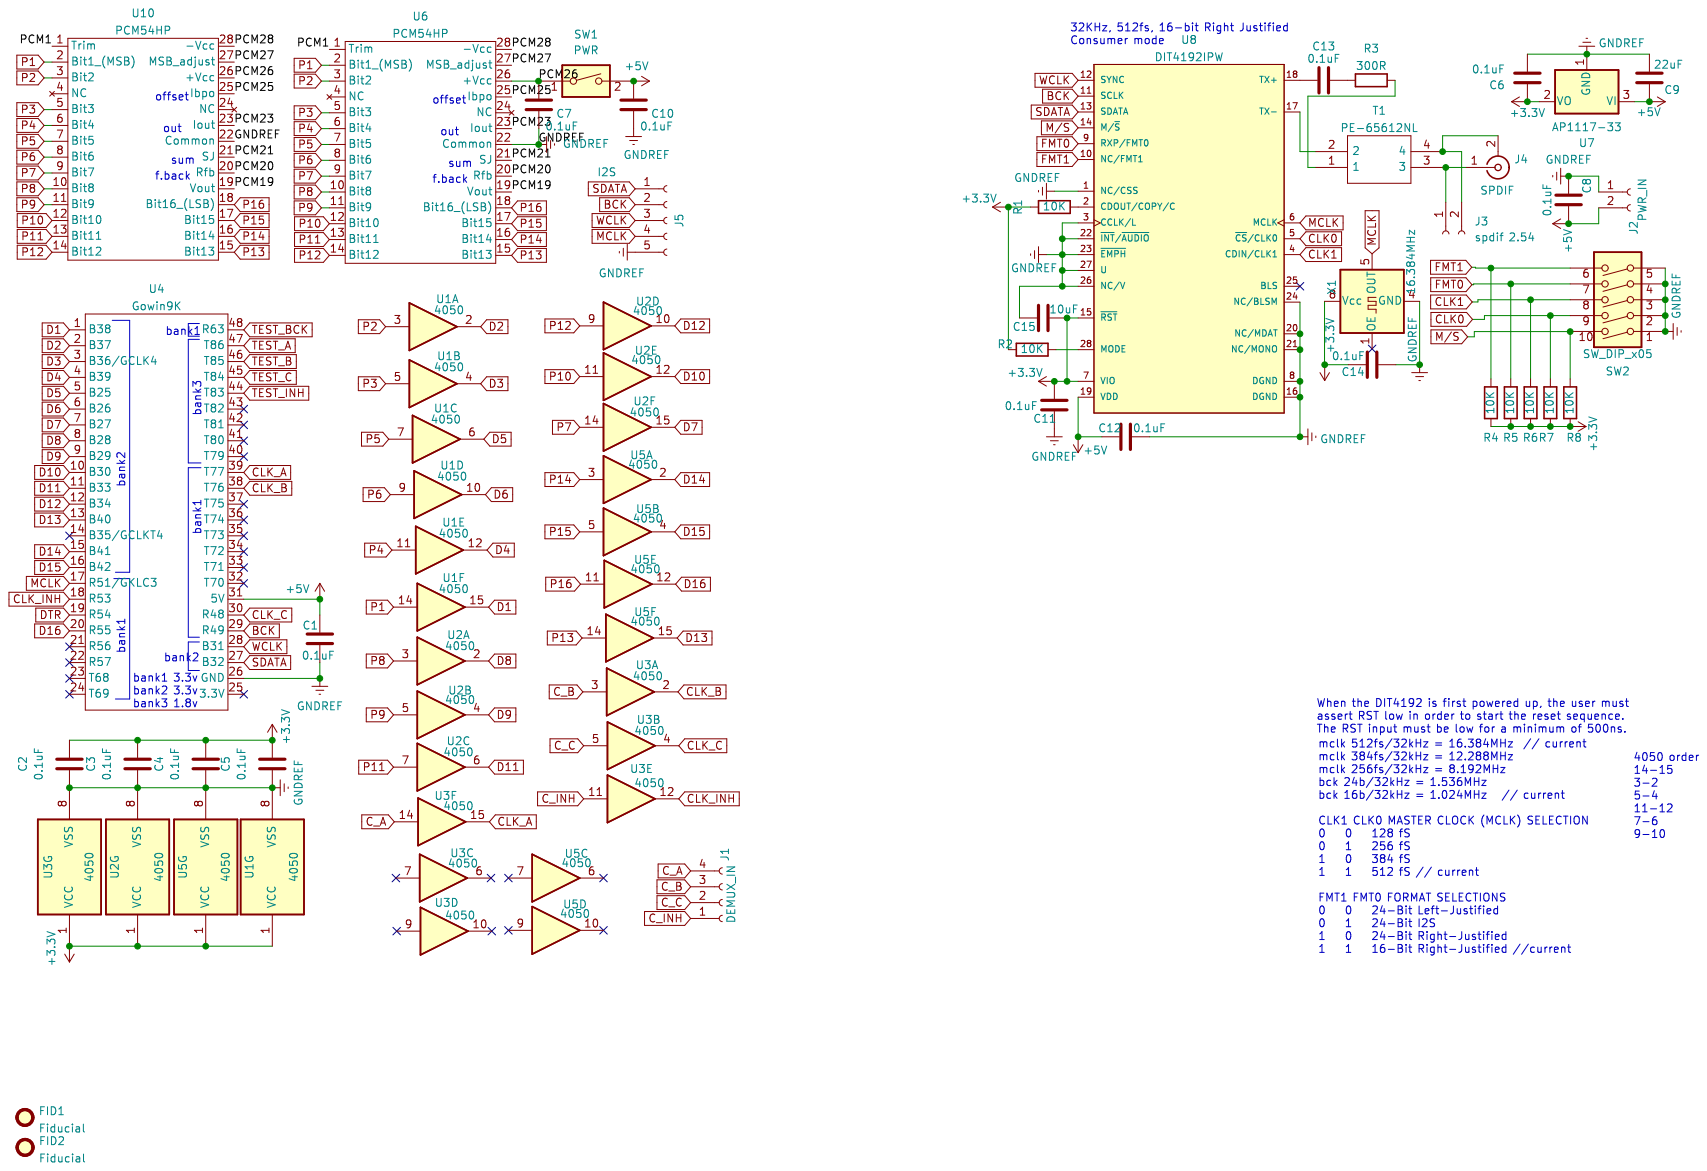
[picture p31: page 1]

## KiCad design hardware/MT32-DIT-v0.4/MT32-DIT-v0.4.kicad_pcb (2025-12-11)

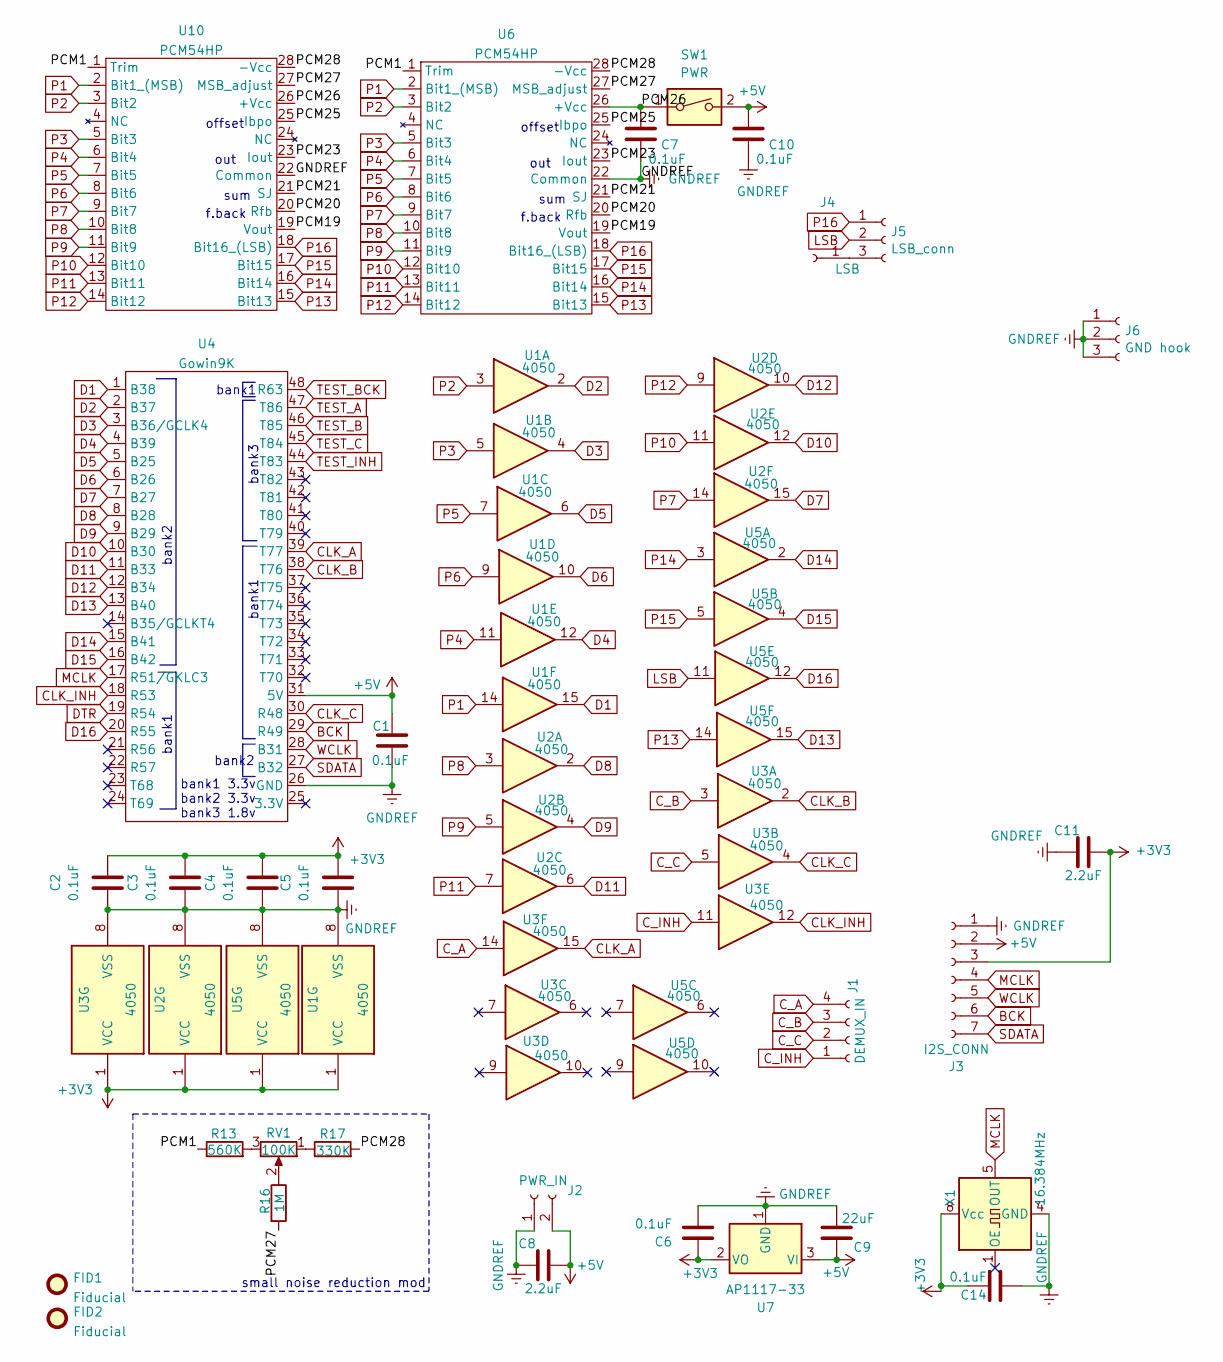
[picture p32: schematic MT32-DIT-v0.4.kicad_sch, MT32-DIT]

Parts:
C1, C2, C3, C4, C5, C6, C7, C10, C14: 0.1uF; C_0402_1005Metric_Pad0.74x0.62mm_HandSolder
C8, C11: 2.2uF; C_0603_1608Metric_Pad1.08x0.95mm_HandSolder
C9: 22uF; CP_EIA-7343-43_Kemet-X_Pad2.25x2.55mm_HandSolder
FID1, FID2: Fiducial; Fiducial_0.5mm_Mask1mm
J1: DEMUX_IN; PinHeader_1x04_P2.54mm_Vertical
J2: PWR_IN; PinHeader_1x02_P2.54mm_Vertical
J3: I2S_CONN; PinHeader_1x07_P2.54mm_Vertical
J4: LSB; PinHeader_1x01_P2.54mm_Vertical
J5: LSB_conn; PinHeader_1x03_P2.54mm_Vertical
J6: GND hook; PinHeader_1x03_P2.54mm_Vertical
R13: 560K; R_0402_1005Metric_Pad0.72x0.64mm_HandSolder
R16: 1M; R_0402_1005Metric_Pad0.72x0.64mm_HandSolder
R17: 330K; R_0402_1005Metric_Pad0.72x0.64mm_HandSolder
RV1: 100K; Potentiometer_Piher_PT-6-H_Horizontal
SW1: PWR; SW_DIP_SPSTx01_Slide_6.7x4.1mm_W7.62mm_P2.54mm_LowProfile
U1, U2, U3, U5: 4050; SO-16_3.9x9.9mm_P1.27mm
U4: Gowin9K; DIP-48_W15.24mm_Socket
U6, U10: PCM54HP; PCM54
U7: AP1117-33; SOT-223-3_TabPin2
X1: 16.384MHz; Oscillator_DIP-8

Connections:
+3V3: C2.1, C3.1, C4.1, C5.1, C6.1, C11.2, C14.2, J3.3, U1.1 (VCC), U2.1 (VCC), U3.1 (VCC), U5.1 (VCC), U7.2 (VO), X1.8 (Vcc)
+5V: C1.2, C8.2, C9.1, C10.1, J2.2, J3.2, SW1.2, U4.31 (5V), U7.3 (VI)
/PCM1: R13.1, U6.1 (Trim), U10.1 (Trim)
/PCM19: U6.19 (Vout), U10.19 (Vout)
/PCM20: U6.20 (Rfb), U10.20 (Rfb)
/PCM21: U6.21 (SJ), U10.21 (SJ)
/PCM23: U6.23 (Iout), U10.23 (Iout)
/PCM25: U6.25 (Ibpo), U10.25 (Ibpo)
/PCM26: C7.1, SW1.1, U6.26 (+Vcc), U10.26 (+Vcc)
/PCM27: R16.2, U6.27 (MSB_adjust), U10.27 (MSB_adjust)
/PCM28: R17.2, U6.28 (-Vcc), U10.28 (-Vcc)
BCK: J3.6, U4.29 (R49)
CLK_A: U3.15, U4.39 (T77)
CLK_B: U3.2, U4.38 (T76)
CLK_C: U3.4, U4.30 (R48)
CLK_INH: U3.12, U4.18 (R53)
C_A: J1.4, U3.14
C_B: J1.3, U3.3
C_C: J1.2, U3.5
C_INH: J1.1, U3.11
D1: U1.15, U4.1 (B38)
D2: U1.2, U4.2 (B37)
D3: U1.4, U4.3 (B36/GCLK4)
D4: U1.12, U4.4 (B39)
D5: U1.6, U4.5 (B25)
D6: U1.10, U4.6 (B26)
D7: U2.15, U4.7 (B27)
D8: U2.2, U4.8 (B28)
D9: U2.4, U4.9 (B29)
D10: U2.12, U4.10 (B30)
D11: U2.6, U4.11 (B33)
D12: U2.10, U4.12 (B34)
D13: U4.13 (B40), U5.15
D14: U4.15 (B41), U5.2
D15: U4.16 (B42), U5.4
D16: U4.20 (R55), U5.12
DTR: U4.19 (R54)
GNDREF: C1.1, C2.2, C3.2, C4.2, C5.2, C6.2, C7.2, C8.1, C9.2, C10.2, C11.1, C14.1, J2.1, J3.1, J6.1, J6.2, J6.3, U1.8 (VSS), U2.8 (VSS), U3.8 (VSS), U4.26 (GND), U5.8 (VSS), U6.22 (Common), U7.1 (GND), U10.22 (Common), X1.4 (GND)
LSB: J5.2, U5.11
MCLK: J3.4, U4.17 (R51/GKLC3), X1.5 (OUT)
unnamed: J4.1, J5.3
unnamed: R13.2, RV1.3
unnamed: R16.1, RV1.2
unnamed: R17.1, RV1.1
P1: U1.14, U6.2 (Bit1_(MSB)), U10.2 (Bit1_(MSB))
P2: U1.3, U6.3 (Bit2), U10.3 (Bit2)
P3: U1.5, U6.5 (Bit3), U10.5 (Bit3)
P4: U1.11, U6.6 (Bit4), U10.6 (Bit4)
P5: U1.7, U6.7 (Bit5), U10.7 (Bit5)
P6: U1.9, U6.8 (Bit6), U10.8 (Bit6)
P7: U2.14, U6.9 (Bit7), U10.9 (Bit7)
P8: U2.3, U6.10 (Bit8), U10.10 (Bit8)
P9: U2.5, U6.11 (Bit9), U10.11 (Bit9)
P10: U2.11, U6.12 (Bit10), U10.12 (Bit10)
P11: U2.7, U6.13 (Bit11), U10.13 (Bit11)
P12: U2.9, U6.14 (Bit12), U10.14 (Bit12)
P13: U5.14, U6.15 (Bit13), U10.15 (Bit13)
P14: U5.3, U6.16 (Bit14), U10.16 (Bit14)
P15: U5.5, U6.17 (Bit15), U10.17 (Bit15)
P16: J5.1, U6.18 (Bit16_(LSB)), U10.18 (Bit16_(LSB))
SDATA: J3.7, U4.27 (B32)
TEST_A: U4.47 (T86)
TEST_B: U4.46 (T85)
TEST_BCK: U4.48 (R63)
TEST_C: U4.45 (T84)
TEST_INH: U4.44 (T83)
WCLK: J3.5, U4.28 (B31)

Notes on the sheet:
sum
f.back
offset
out
bank3
bank2
small noise reduction mod
bank1 3.3v bank2 3.3v bank3 1.8v
bank1

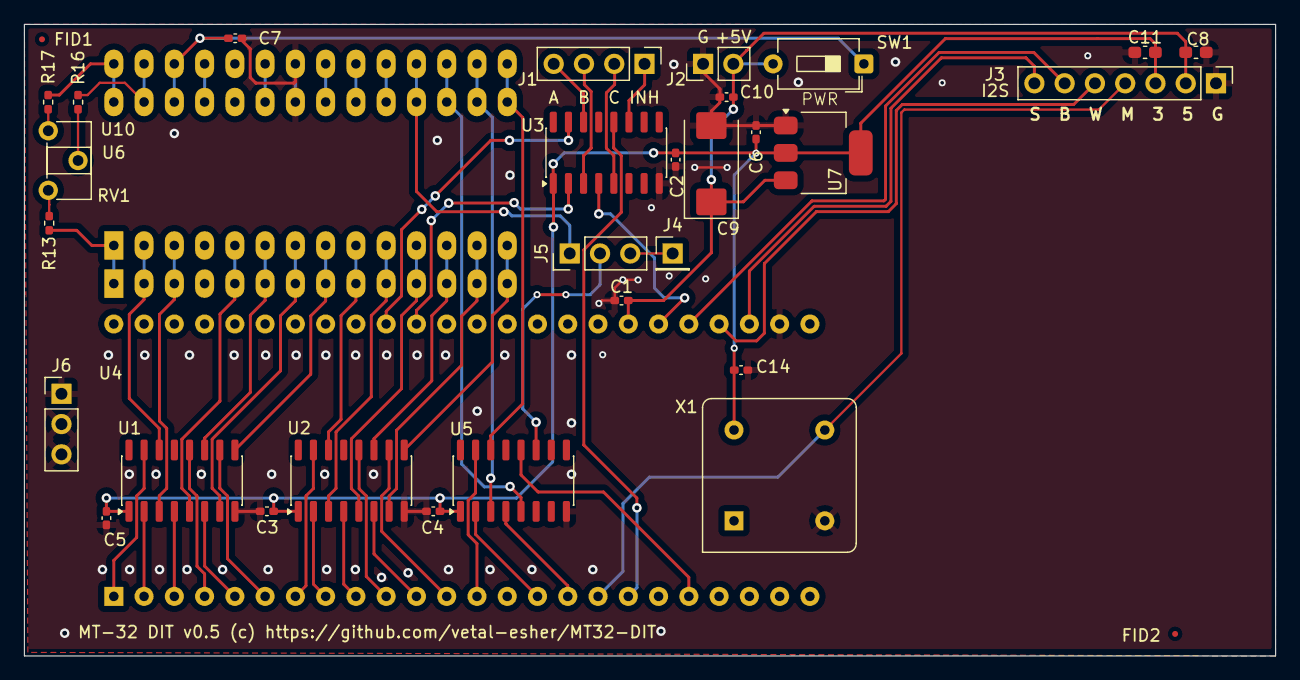
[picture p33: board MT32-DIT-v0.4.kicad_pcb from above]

Board: 2 copper layers, 105.0 x 53.0 mm, 34 parts (0 on the bottom side), 61 nets.

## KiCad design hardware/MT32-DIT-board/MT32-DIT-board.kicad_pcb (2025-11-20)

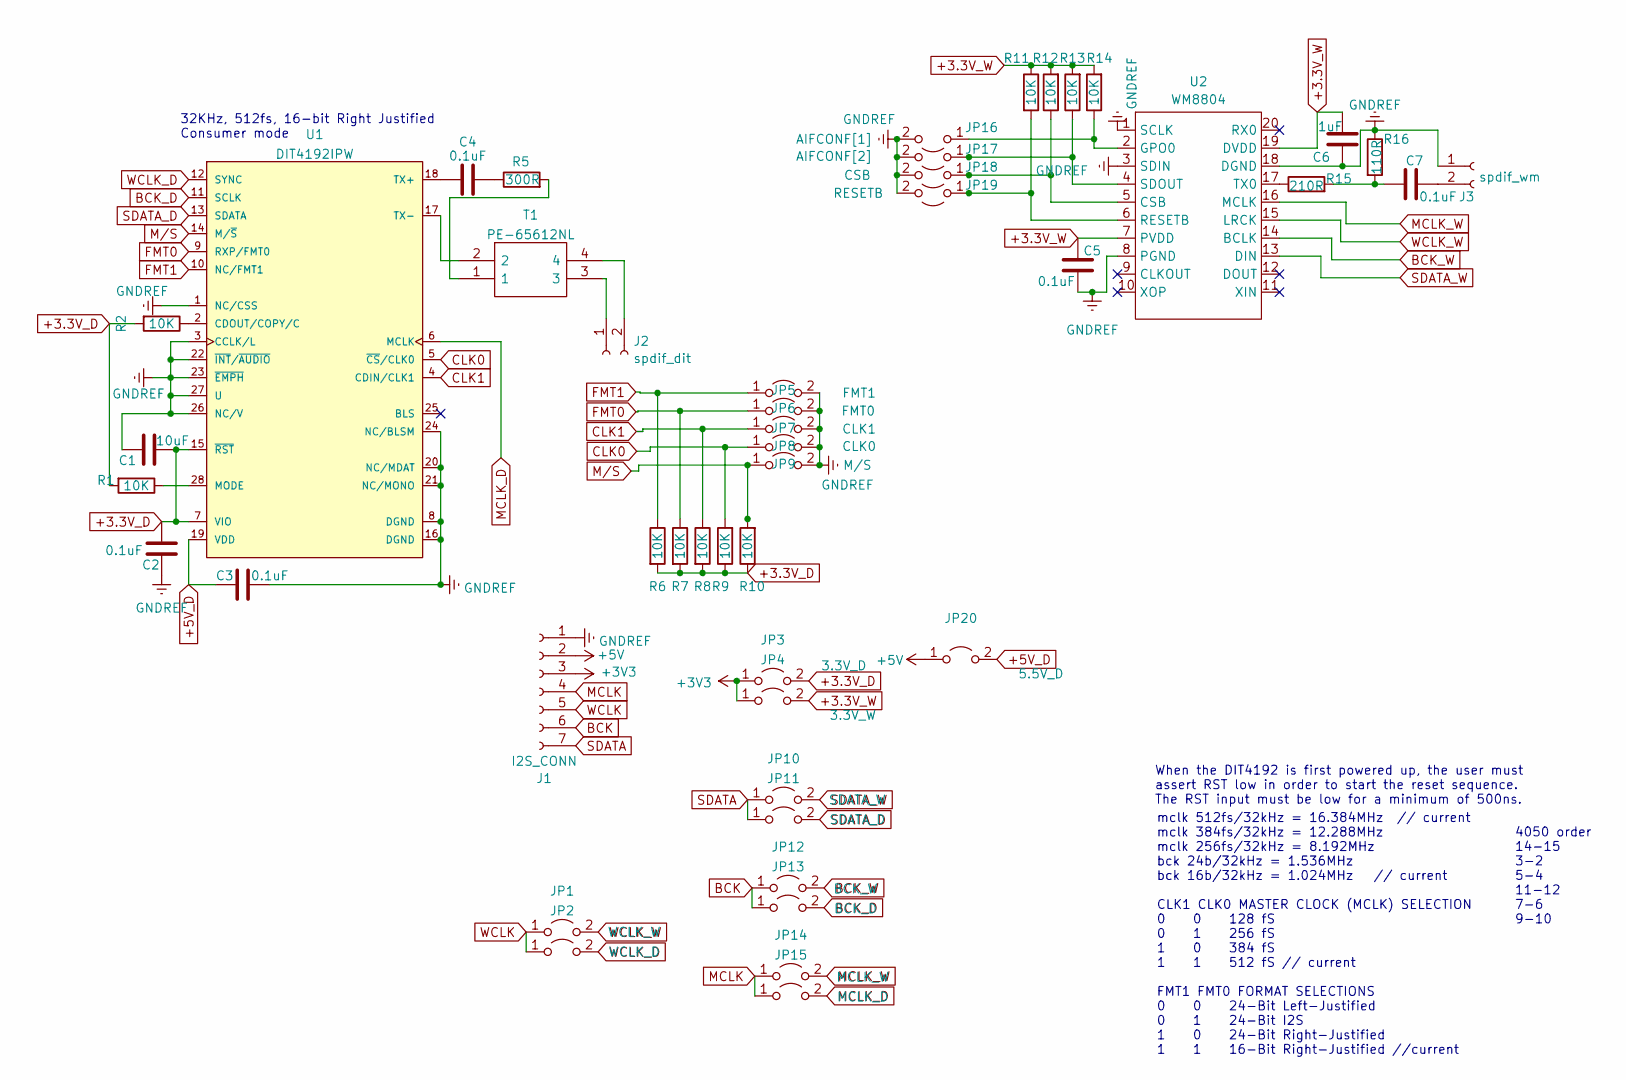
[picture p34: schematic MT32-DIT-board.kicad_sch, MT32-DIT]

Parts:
C1: 10uF; C_0402_1005Metric_Pad0.74x0.62mm_HandSolder
C2, C3, C4, C5, C7: 0.1uF; C_0402_1005Metric_Pad0.74x0.62mm_HandSolder
C6: 1uF; C_0603_1608Metric_Pad1.08x0.95mm_HandSolder
J1: I2S_CONN; PinHeader_1x07_P2.54mm_Vertical
J2: spdif_dit; PinHeader_1x02_P2.54mm_Vertical
J3: spdif_wm; PinHeader_1x02_P2.54mm_Vertical
JP1: WCLK_W; SolderJumper-2_P1.3mm_Open_Pad1.0x1.5mm
JP2: WCLK_D; SolderJumper-2_P1.3mm_Open_Pad1.0x1.5mm
JP3: 3.3V_D; SolderJumper-2_P1.3mm_Open_Pad1.0x1.5mm
JP4: 3.3V_W; SolderJumper-2_P1.3mm_Open_Pad1.0x1.5mm
JP5: FMT1; SolderJumper-2_P1.3mm_Open_Pad1.0x1.5mm
JP6: FMT0; SolderJumper-2_P1.3mm_Open_Pad1.0x1.5mm
JP7: CLK1; SolderJumper-2_P1.3mm_Open_Pad1.0x1.5mm
JP8: CLK0; SolderJumper-2_P1.3mm_Open_Pad1.0x1.5mm
JP9: M/S; SolderJumper-2_P1.3mm_Open_Pad1.0x1.5mm
JP10: SDATA_W; SolderJumper-2_P1.3mm_Open_Pad1.0x1.5mm
JP11: SDATA_D; SolderJumper-2_P1.3mm_Open_Pad1.0x1.5mm
JP12: BCK_W; SolderJumper-2_P1.3mm_Open_Pad1.0x1.5mm
JP13: BCK_D; SolderJumper-2_P1.3mm_Open_Pad1.0x1.5mm
JP14: MCLK_W; SolderJumper-2_P1.3mm_Open_Pad1.0x1.5mm
JP15: MCLK_D; SolderJumper-2_P1.3mm_Open_Pad1.0x1.5mm
JP16: AIFCONF[1]; SolderJumper-2_P1.3mm_Open_Pad1.0x1.5mm
JP17: AIFCONF[2]; SolderJumper-2_P1.3mm_Open_Pad1.0x1.5mm
JP18: CSB; SolderJumper-2_P1.3mm_Open_Pad1.0x1.5mm
JP19: RESETB; SolderJumper-2_P1.3mm_Open_Pad1.0x1.5mm
JP20: 5.5V_D; SolderJumper-2_P1.3mm_Open_Pad1.0x1.5mm
R1, R2, R6, R7, R8, R9, R10, R11, R12, R13, R14: 10K; R_0402_1005Metric_Pad0.72x0.64mm_HandSolder
R5: 300R; R_0402_1005Metric_Pad0.72x0.64mm_HandSolder
R15: 210R; R_0402_1005Metric_Pad0.72x0.64mm_HandSolder
R16: 110R; R_0402_1005Metric_Pad0.72x0.64mm_HandSolder
T1: PE-65612NL; PE65612NL; Manufacturer_Part_Number PE-65612NL; Mouser Part Number 673-PE-65612NL
U1: DIT4192IPW; SSOP-28_3.9x9.9mm_P0.635mm
U2: WM8804; SSOP-20_5.3x7.2mm_P0.65mm

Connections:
+3.3V_D: C1.2, C2.2, JP3.2 (B), R1.2, R2.2, R6.2, R7.2, R8.2, R9.1, R10.1, U1.7 (VIO), U1.15 (~RST)
+3.3V_W: C5.2, C6.1, JP4.2 (B), R11.1, R12.2, R13.2, R14.2, U2.7 (PVDD), U2.19 (DVDD)
+3V3: J1.3, JP3.1 (A), JP4.1 (A)
+5V: J1.2, JP20.1 (A)
+5V_D: C3.1, JP20.2 (B), U1.19 (VDD)
BCK: J1.6, JP12.1 (A), JP13.1 (A)
BCK_D: JP13.2 (B), U1.11 (SCLK)
BCK_W: JP12.2 (B), U2.14 (BCLK)
CLK0: JP8.1 (A), R9.2, U1.5 (~CS/CLK0)
CLK1: JP7.1 (A), R8.1, U1.4 (CDIN/CLK1)
FMT0: JP6.1 (A), R7.1, U1.9 (RXP/FMT0)
FMT1: JP5.1 (A), R6.1, U1.10 (NC/FMT1)
GNDREF: C1.1, C2.1, C3.2, C5.1, C6.2, J1.1, J3.1, JP5.2 (B), JP6.2 (B), JP7.2 (B), JP8.2 (B), JP9.2 (B), JP16.2 (B), JP17.2 (B), JP18.2 (B), JP19.2 (B), R16.1, U1.1 (NC/CSS), U1.3 (CCLK/L), U1.8 (DGND), U1.16 (DGND), U1.20 (NC/MDAT), U1.21 (NC/MONO), U1.22 (~INT/~AUDIO), U1.23 (~EMPH), U1.24 (NC/BLSM), U1.26 (NC/V), U1.27 (U), U2.1 (SCLK), U2.3 (SDIN), U2.8 (PGND), U2.18 (DGND)
MCLK: J1.4, JP14.1 (A), JP15.1 (A)
MCLK_D: JP15.2 (B), U1.6 (MCLK)
MCLK_W: JP14.2 (B), U2.16 (MCLK)
M/S: JP9.1 (A), R10.2, U1.14 (M/~S)
unnamed: C4.1, R5.1
unnamed: C7.2, R15.2, R16.2
unnamed: J2.1, T1.3
unnamed: J2.2, T1.4
unnamed: C7.1, J3.2
unnamed: JP16.1 (A), R14.1, U2.2 (GPO0)
unnamed: JP17.1 (A), R13.1, U2.4 (SDOUT)
unnamed: JP18.1 (A), R12.1, U2.5 (CSB)
unnamed: JP19.1 (A), R11.2, U2.6 (RESETB)
unnamed: R5.2, T1.1
unnamed: R2.1, U1.2 (CDOUT/COPY/C)
unnamed: R1.1, U1.28 (MODE)
unnamed: C4.2, U1.18 (TX+)
unnamed: T1.2, U1.17 (TX-)
unnamed: R15.1, U2.17 (TX0)
SDATA: J1.7, JP10.1 (A), JP11.1 (A)
SDATA_D: JP11.2 (B), U1.13 (SDATA)
SDATA_W: JP10.2 (B), U2.13 (DIN)
WCLK: J1.5, JP1.1 (A), JP2.1 (A)
WCLK_D: JP2.2 (B), U1.12 (SYNC)
WCLK_W: JP1.2 (B), U2.15 (LRCK)

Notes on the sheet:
mclk 512fs/32kHz = 16.384MHz // current mclk 384fs/32kHz = 12.288MHz mclk 256fs/32kHz = 8.192MHz bck 24b/32kHz = 1.536MHz bck 16b/32kHz = 1.024MHz // current CLK1 CLK0 MASTER CLOCK (MCLK) SELECTION 0 0 128 fS 0 1 256 fS 1 0 384 fS 1 1 512 fS // current FMT1 FMT0 FORMAT SELECTIONS 0 0 24-Bit Left-Ju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
4050 order 14-15 3-2 5-4 11-12 7-6 9-10
32KHz, 512fs, 16-bit Right Justified Consumer mode
When the DIT4192 is first powered up, the user must assert RST low in order to start the reset sequence. The RST input must be low for a minimum of 500ns.

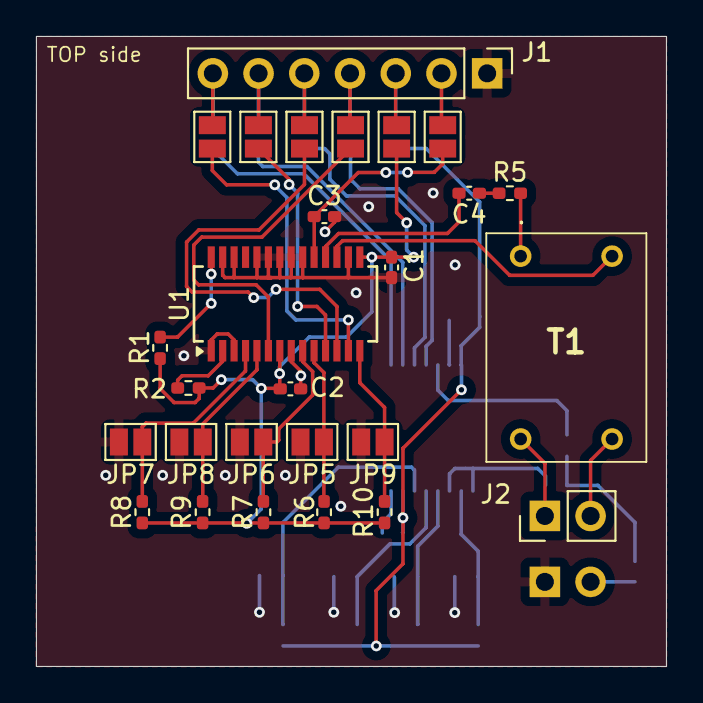
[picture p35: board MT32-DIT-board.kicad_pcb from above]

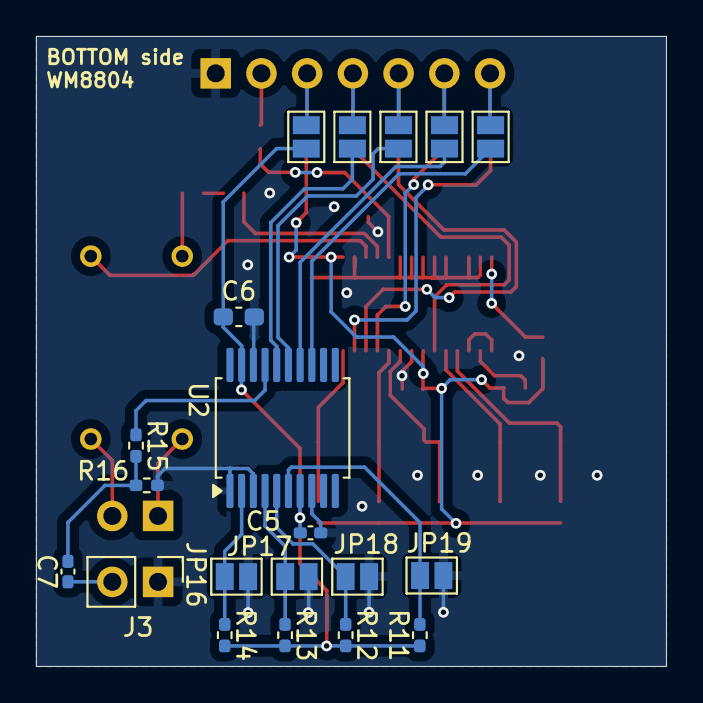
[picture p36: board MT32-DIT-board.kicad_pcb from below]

Board: 2 copper layers, 35.0 x 35.0 mm, 47 parts (20 on the bottom side), 38 nets.

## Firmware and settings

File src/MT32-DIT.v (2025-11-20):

//Roland MT-32 parallel DAC data converter to 16 bit right justified for Digital Audio Transmitters

module dac_decoder (
        input wire rst_n,		//reset signal
        input rev_sw,           	//reverb switch
        input clk_inh,			//256kHz INH clk input
        input [2:0] ch_id,		//cd4051 sample/hold controls a/b/c
        input signed [15:0] dac,	//parallel input from dac
        input drq,                 	//data request
        output reg dtr,             	//data ready flag
        output reg [31:0] data		//32 bit dac output
);
reg signed [15:0] lsyn1, lsyn2, rsyn1, rsyn2, rrev;	//channels from LA32 and Reverb ICs
reg signed [15:0] left,right;
reg signed [16:0] l,r;

initial begin
    data<=0; rrev<=0; rsyn1<=0; lsyn2<=0; rsyn2<=0; 
    l<=0; r<=0; left<=0; right<=0; dtr<=0;
end

localparam signed [15:0] OFFSET = 16'd8192; //Digital DC offset fix

always  @(negedge clk_inh) begin
	if (!rst_n) begin
		data<=0; dtr<=0;
	end else begin
	case (ch_id)
     		7 : begin // RSYN1
			rsyn1<=dac; dtr<=1;
			left <= l[15:0]-OFFSET; right <= r[15:0]-OFFSET;
		    end 
		6 : begin rsyn2<=dac; dtr<=0; end // RSYN2
		5 : begin data<={left,right}; dtr<=0; end // empty
		4 : begin dtr<=1; end // empty
		3 : begin lsyn1<=dac; dtr<=1; end // LSYN1
		2 : begin lsyn2<=dac; dtr<=1; end // LSYN2
		1 : begin rrev<=dac;  dtr<=1; end // RREV
		0 : begin dtr<=0; // LREV
			if (!rev_sw) begin  l<=lsyn1; r<=rsyn1;  end else 
			begin l<=lsyn1+lsyn2+dac; r<=rsyn1+rsyn2+rrev; end
 	     	end 
	endcase
	end
end
endmodule

module i2s_serializer (
        input wire rst_n,		//reset signal
        input mclk,			//master clock 16.384MHz
        input [31:0] data,		//input data 
        input dtr,              	//data ready flag
        output reg drq, 		//data request
        output reg sdata,		//i2s sdata output
        output reg wclk,		//i2s word select lrck output mclk/512 = 32kHz
        output bck			//i2s bit clock output //16bit * 2 * 32000 = 1.024 MHz (16.384/16)
);
reg [31:0] mclk_counter;       		//32bit counter
wire bck_int = mclk_counter[3];    	//OSC divide
BUFG bck_bufg_inst (.I(bck_int), .O(bck));
reg [31:0] data_buf;	    		//i2s output buffer 
reg [31:0] data_int;	    		//i2s input buffer 
reg [4:0] cbit;				        //current bit counter

always  @(posedge mclk) begin			
	if (!rst_n) begin mclk_counter<=0; end 
	else begin 
		mclk_counter<=mclk_counter+1;
        	if (dtr==1 && drq==0) begin data_int<=data; end
	end
    
end

always  @(negedge bck_int) begin
	if (!rst_n) begin 
		cbit<=0; wclk<=0; data_buf<=0;
	end else begin 
		if (wclk==0) begin sdata<=data_buf[31-cbit]; end 	//LSYN send
		else if (wclk==1) begin sdata<=data_buf[15-cbit]; end	//RSYN send

		cbit<=cbit+4'b01;

		if (cbit==15 && wclk==0) begin //LSYN end
			cbit<=0; wclk<=1; drq<=0; 
		end		        	
		else if (cbit==15 && wclk==1) begin //RSYN end, new buffer read
			cbit<=0; wclk<=0; drq<=1; data_buf<=data_int; 
		end else begin drq<=0; end
 	end
end
endmodule


module top 	(
        input mclk,             //master clock 16.384MHz //pin 51
        input clk_inh,          //256kHz INH clk input   //pin 53
        input [2:0] ch_id,      //cd4051 a/b/c 128/64/32kHz //pin a 77 b 76 c 48
        input signed [15:0] dac,//parallel input from dac
        input sys_rst_n,        //reset input
        input rev_sw,           //reverb switch
        output wire drq,        //data request //pin 69
        output wire dtr,        //data write   //pin 68
        output sdata,           //16bit RJ sdata output  //pin32
        output wire wclk,       //word select lrck output 32kHz //pin31
        output wire bck         //bit clock output 1024MHz //pin49
);
wire [31:0] data;

dac_decoder dac1(
    .clk_inh(clk_inh),.ch_id(ch_id),.dac(dac),.data(data),.rst_n(sys_rst_n),.rev_sw(rev_sw),.drq(drq),.dtr(dtr)
);
i2s_serializer ser1 (
	.mclk(mclk),.sdata(sdata),.wclk(wclk),.bck(bck),.data(data),.rst_n(sys_rst_n),.drq(drq),.dtr(dtr)
);

endmodule

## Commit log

2024-12-06 Add files via upload
    MT32-DIT-module is the main board with FPGA part. Note that the DIT part is splitted into MT32-DIT-board Kicad project.
    [mt-32DIT-module-B_Cu.gbr, mt-32DIT-module-B_Mask.gbr, mt-32DIT-module-B_Paste.gbr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]
2024-12-06 Delete hardware/datasheets/MT32-DIT-module directory
    Uploaded by mistake
    [mt-32DIT-module-B_Cu.gbr, mt-32DIT-module-B_Mask.gbr, mt-32DIT-module-B_Paste.gbr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]
2024-12-06 Add files via upload
    MT32-DIT-board is the DIT part of the project, small addon card with I2S connector to the MT32-DIT-module.
    [MT32-DIT-board.kicad_pcb, MT32-DIT-board.kicad_sch, MT32-DIT-board.xlsx]
2024-12-06 Add files via upload
    MT32-DIT-module is the main board with FPGA part which provide I2S output. Small DIT-card with any I2S-to-SPDIF DIT can be designed or MT32-DIT-board can be used.
    [mt-32DIT-module-B_Cu.gbr, mt-32DIT-module-B_Mask.gbr, mt-32DIT-module-B_Paste.gbr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]
2024-12-06 Add files via upload
    Verilog project for MT32-DIT.
    MT32-DIT.fs is precompiled firmware to use the pins designed in Kicad.
2024-12-06 Delete hardware/MT32-DIT-module directory
    Found newest project for reupload
    [mt-32DIT-module-B_Cu.gbr, mt-32DIT-module-B_Mask.gbr, mt-32DIT-module-B_Paste.gbr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]
2024-12-06 Add files via upload
    MT32-DIT-module FPGA part
    [MT32-DIT-v0.4.kicad_pcb, MT32-DIT-v0.4.kicad_sch]
2024-12-07 M/S pin was not connected due to Kicad terrible grid, fixed
    [MT32-DIT-board.kicad_pcb, MT32-DIT-board.kicad_sch]
2025-10-15 Verilog rewrite
    Clean debug pins
    Fix OFFSET as localparam
    Rewrite DAC decoder and I2S serializer
    [MT32-DIT.v]
2025-10-15 dac_decoder logics update
    Changes in actions in order of case (ch_id).
    Frame_sent flag added to retry update data register if i2s_serializer is also in update stage (drq is high).
    Added reset switch to mclk cycle.
2025-10-22 Update MT32-DIT.v
    DAC frames are now considered as signed.
2025-11-20 Kicad 9.0.5 update
    Kicad update to 9.0.5
    Src change: dtr is back, second buffer register added
    [MT32-DIT-board.kicad_pcb, MT32-DIT-board.kicad_sch, MT32-DIT-v0.4.kicad_pcb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]
2025-12-11 HW updates
    Service notes 2nd and 3rd editions added. Kicad schematic update - LSB bit route can be selected for external input.
    [MT32-DIT-v0.4.kicad_pcb, MT32-DIT-v0.4.kicad_sch]
